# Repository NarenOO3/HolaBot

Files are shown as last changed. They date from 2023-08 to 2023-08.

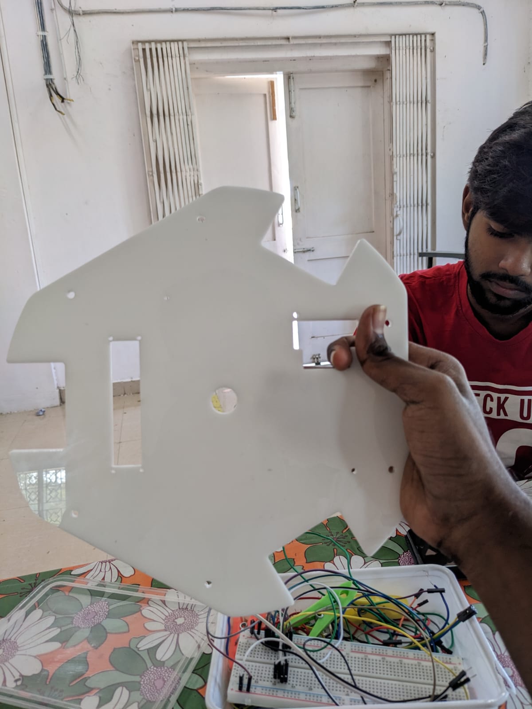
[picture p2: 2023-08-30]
Design Files/Lazer cut part.jpeg

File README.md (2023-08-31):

# HolaBot...
Hola bot is a 3- wheeled holonomic drive robot which can control all three degrees of freedom possible on a plane (Translation along the x and y-axis and rotation along the z-axis). Ultimately, we were required to create a Hola bot to draw complex art in the given plane. We did this Project as a team of four People for a competition called [eyantra](https://portal.e-yantra.org/)
# Video Demo (fast-forwarded)...

**Complete Hola Bot**

https://github.com/NarenOO3/HolaBot/assets/98276114/a756ce81-f39d-4ce2-9923-da0e97ca74d5

**Infinity Symbol**

https://github.com/NarenOO3/HolaBot/assets/98276114/4b2ce358-d221-415d-9932-d4c478116c63

# **Skills Learned :**
Linux, ROS, Gazebo, Solid Modeling, Python Programming, Arduino & C programming

# **Working Principle**
**Flow Chart**
Untitled Diagram drawio (1)

Initially the over Headcamera detect the aruco markers in the canvas and the aruco marker in the hola bot and send this information to the python node where we find the coordinates(x,y) of the Hola bot

| Arena (Canvas) |Aruco Markers |
| --- | --- |
| arena hola | Hola bot and aruco markers |

Then we will feed the picture that we like to draw as a contour and get the coordinates of the points in the contour which the holabot will draw and Using PID controller script,which subcribe the coordinates data of holabot from Over headcamera detection script, the Speed for the three stepper motor is decided which is sent to ESP32 in the hola bot via **wifi** through Socket Programming.

The Speed values in Esp32 will be send to ATmega2560 via hardware serial communication and Atmega2560 will control the stepper motors via A4988 Stepper Drivers.

# Design Pictures (done in Fusion 360)
| | |
| --- | --- |
| Chassis body final new v20 | Chassis body final new v23 |

# Gazebo Simulation Video
https://github.com/NarenOO3/HolaBot/assets/98276114/66dbb890-16b2-4fda-85fd-7b0090c1bab6

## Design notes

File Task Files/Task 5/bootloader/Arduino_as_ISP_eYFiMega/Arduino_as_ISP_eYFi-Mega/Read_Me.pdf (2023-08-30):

Flashing eYFi-Mega ATmega 2560 Bootloader using Arduino IDE

Note: Follow the procedure given below on Windows operating system ONLY.

### 1. Download Arduino IDE

Make sure you have Arduino IDE installed on your Windows system. If not, you can download it from https://www.arduino.cc/en/Main/Software.

### 2. Connections of Arduino Mega and eYFi-Mega board

Grab an Arduino Mega board. Make the connections as shown in below Fig. 1.

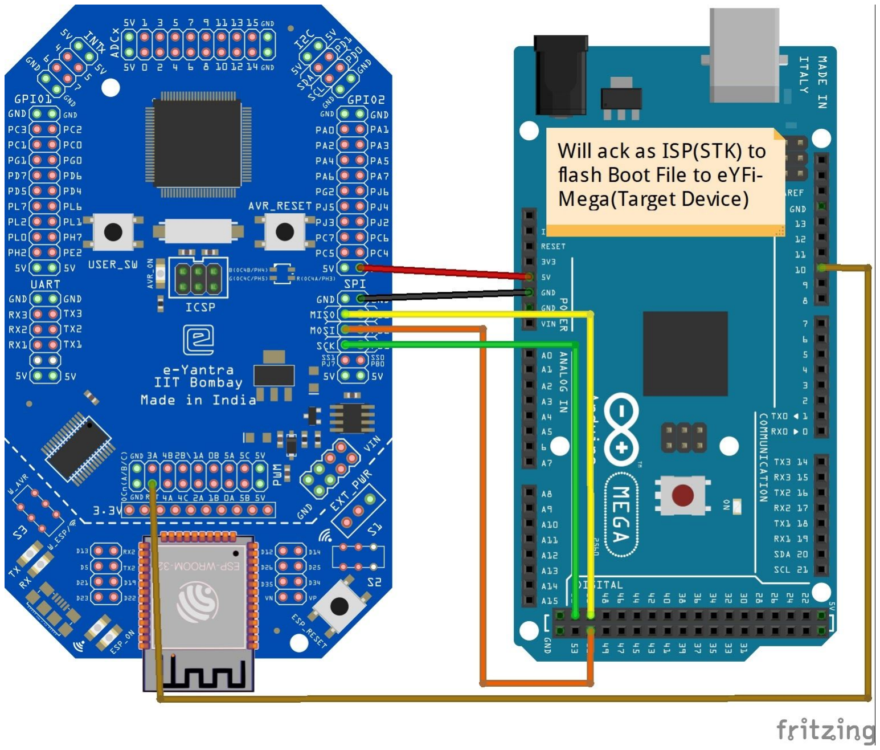
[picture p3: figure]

Fig. 1: Arduino as ISP Connections with eYFi-Mega board

### 3. Upload Arduino as ISP

Open the Arduino IDE. In the menu, select File > Examples > 11.ArduinoISP > ArduinoISP to open up the Arduino as ISP sketch.

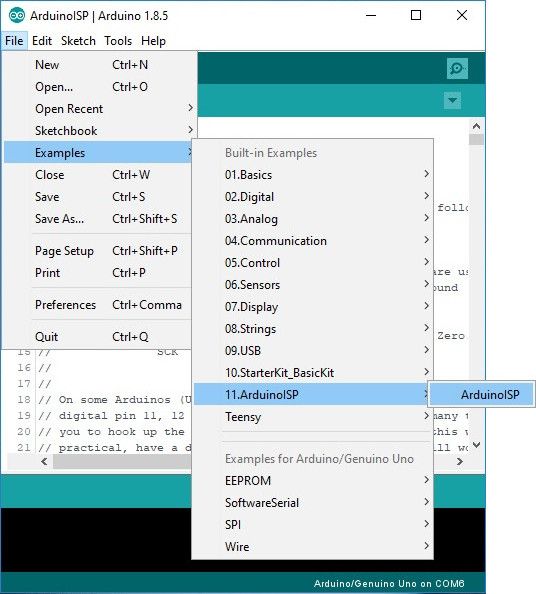
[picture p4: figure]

Select the COM port for your Arduino as ISP. The COM port may be different depending on how it is enumerated on your computer.
Note: Remember the COM port as it will be required in further sections.

Upload the code to your Arduino Mega to turn it into a AVRISP.

### 4. Burning a Bootloader to Your Target (eYFi-Mega)

Download the zip file “Arduino_as_ISP_eYFi-Mega” from the Downloads section of the link: http://products.e-yantra.org/.

Right-click on the file: fuseset.bat and click on Edit, this will open the file in Notepad to edit it.

First find the COM Port where the Arduino Mega board is connected to your system.
Edit the the command provided in the file and replace the default COM Port which is “COM58” and replace it with your COM Port. Save the files. Do Not change any other part of the command provided.

Repeat this step with the file: hexflash.bat, save the file after editing.

Open the Command Prompt, navigate to the Arduino_as_ISP_eYFi-Mega folder and run these two commands in the following order:
a. fuseset.bat
b. hexflash.bat

Expected Output after executing:

a. fuseset.bat

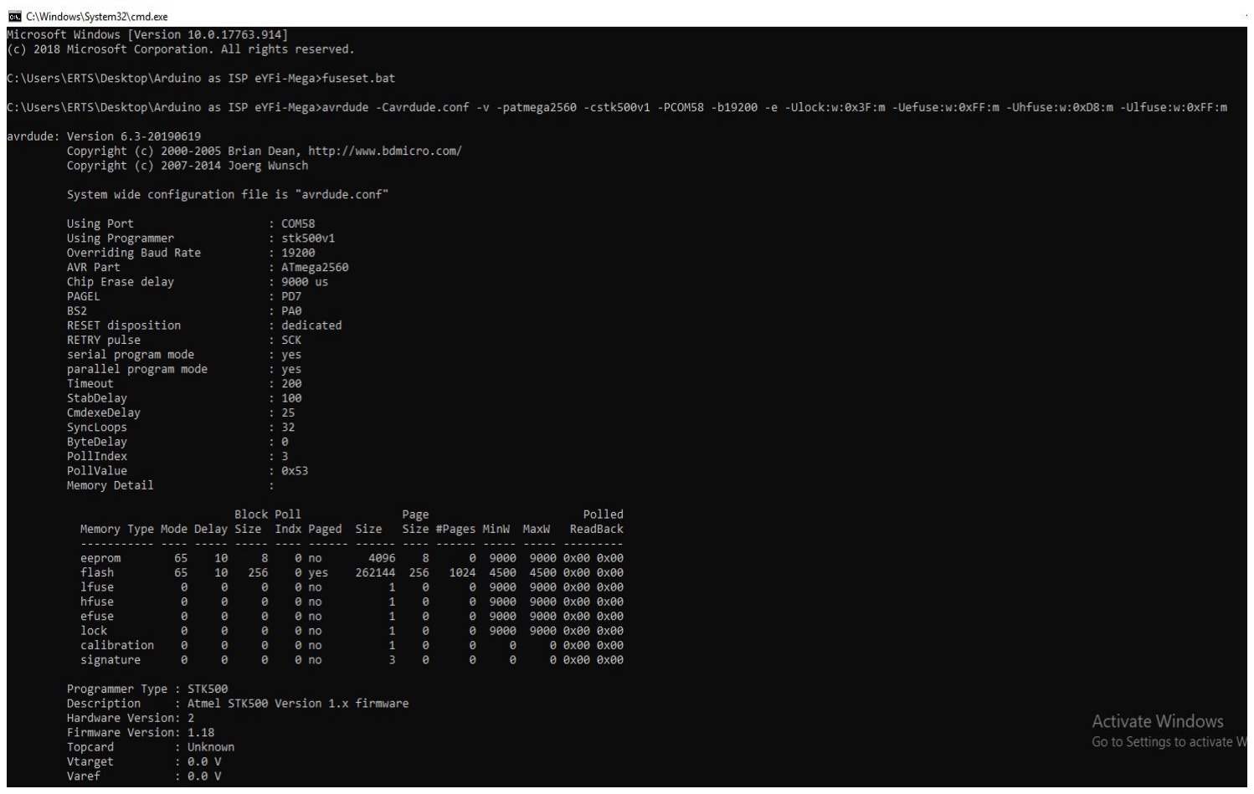
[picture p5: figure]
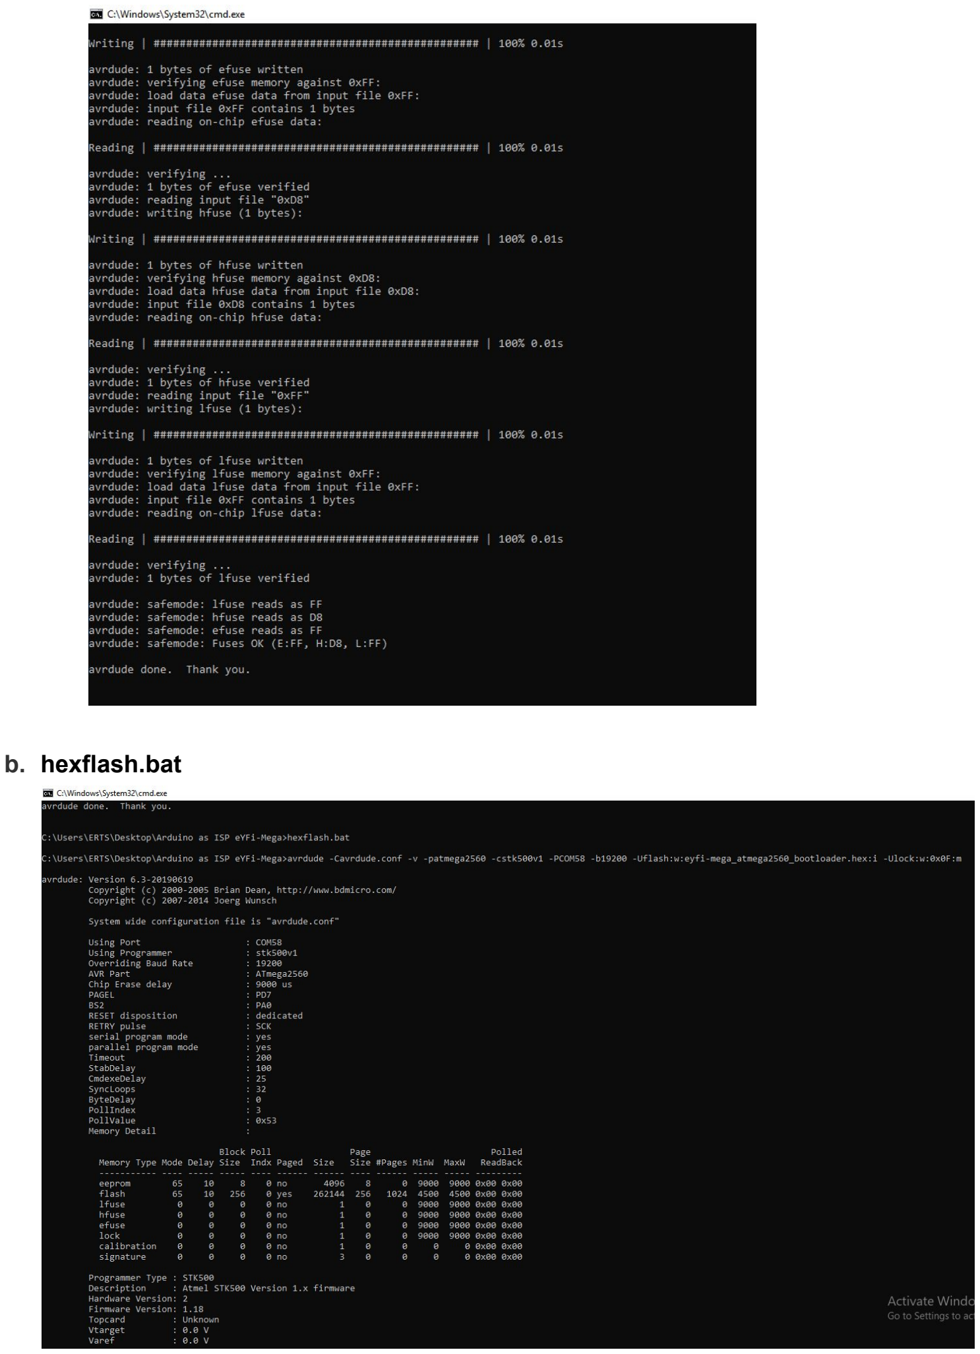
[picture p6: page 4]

b. hexflash.bat

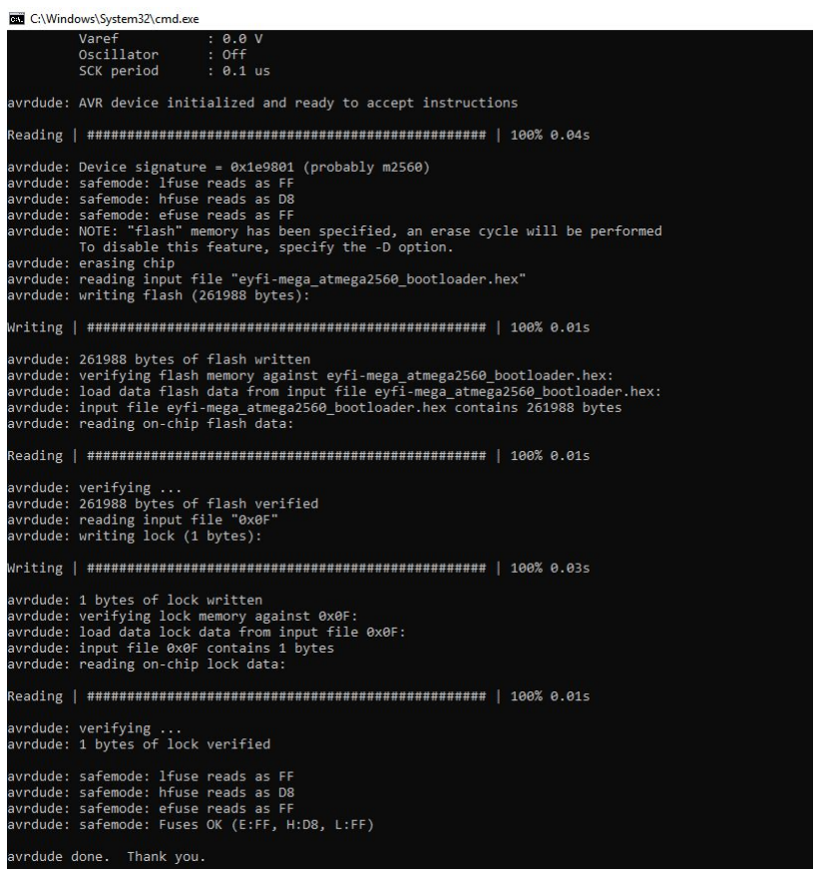
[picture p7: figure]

Once you get this similar output on your Command Prompt, this means that the eYFi-Mega ATmega2560 Bootloader has been flashed successfully on your board.

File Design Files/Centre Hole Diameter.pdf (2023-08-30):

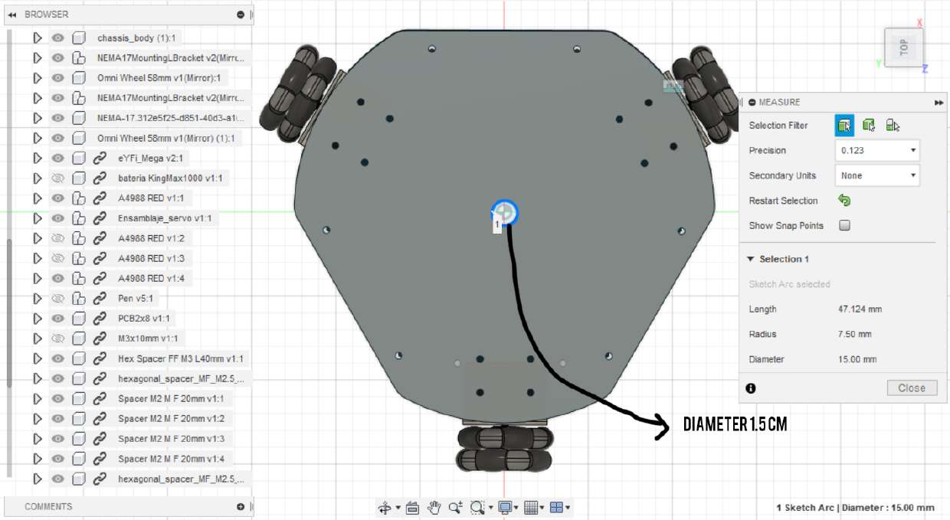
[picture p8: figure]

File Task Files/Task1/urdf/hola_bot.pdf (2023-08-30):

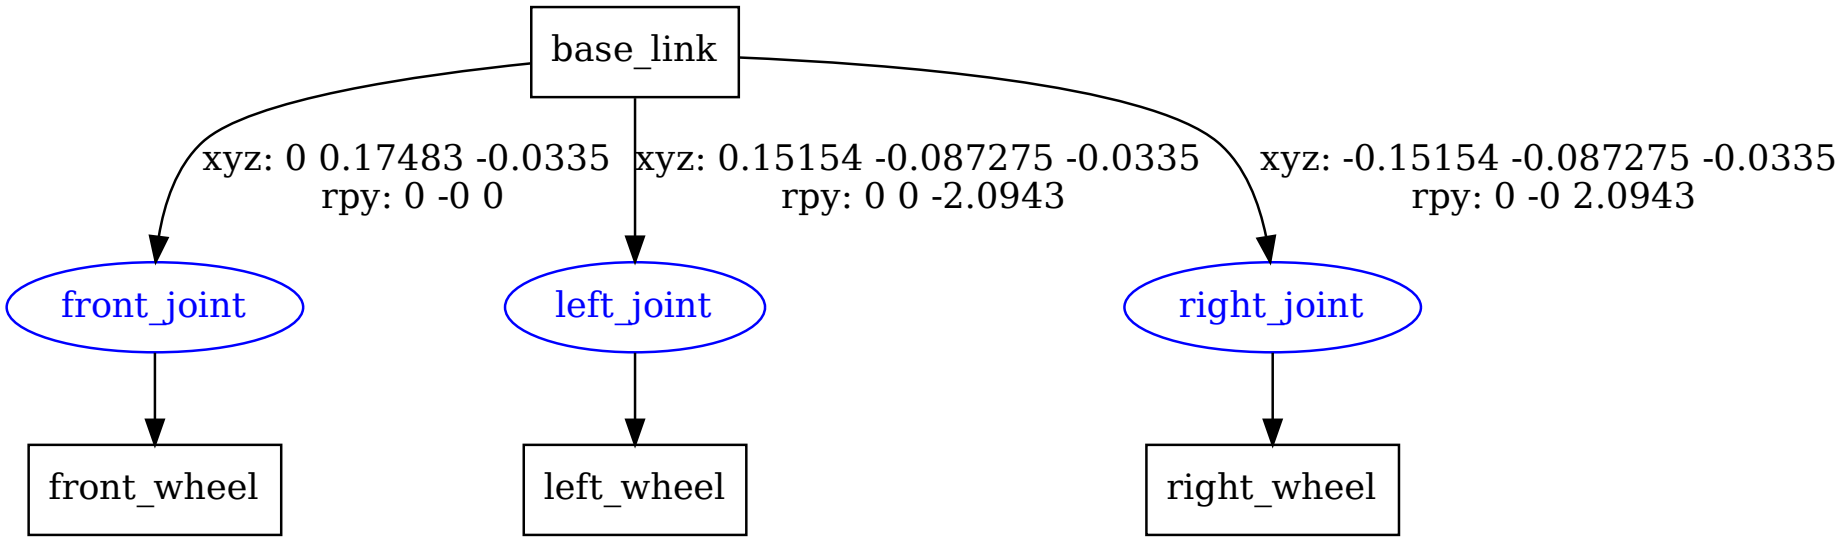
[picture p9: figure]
base_link; front_joint; xyz: 0 0.17483 -0.0335 rpy: 0 -0 0; left_joint; xyz: 0.15154 -0.087275 -0.0335 rpy: 0 0 -2.0943; right_joint; xyz: -0.15154 -0.087275 -0.0335 rpy: 0 -0 2.0943; front_wheel; left_wheel; right_wheel

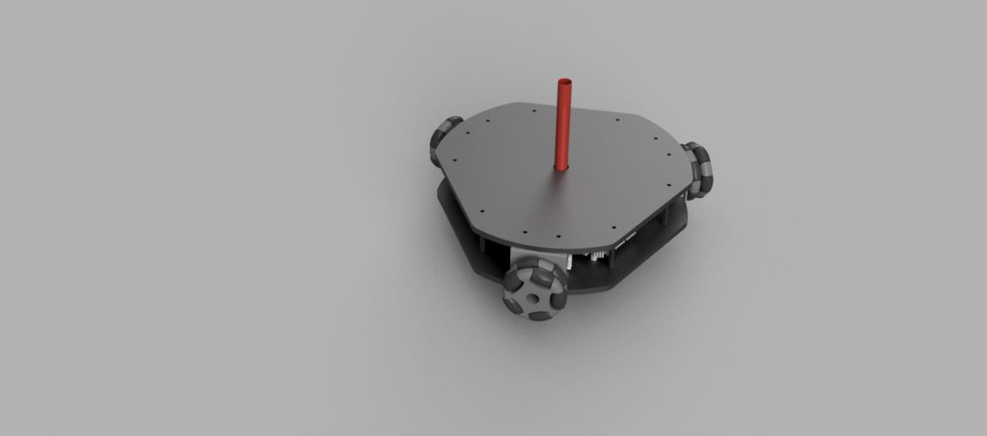
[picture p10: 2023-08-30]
Design Files/3D render of Design 8.jpeg

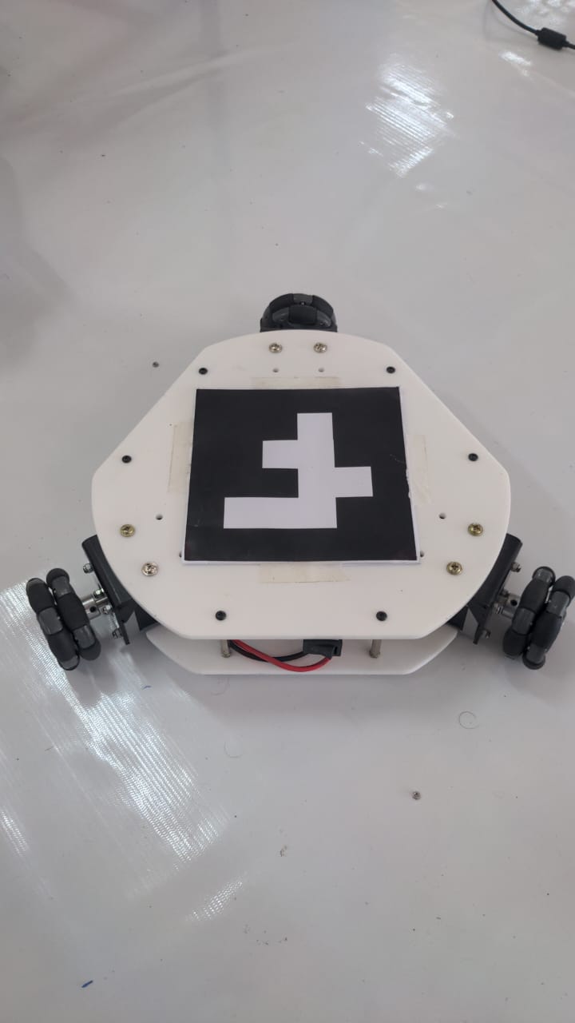
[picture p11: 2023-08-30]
Design Files/HolaBot.jpeg

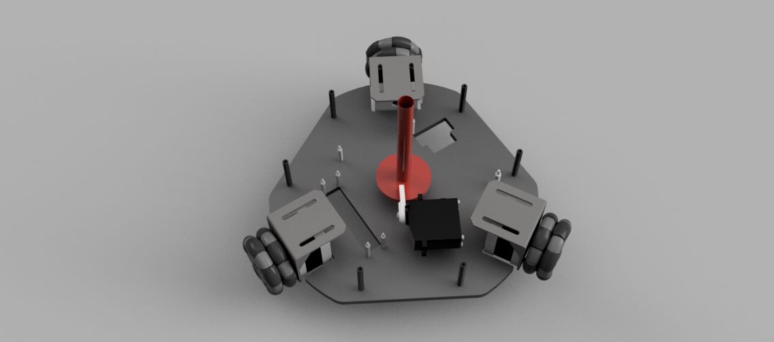
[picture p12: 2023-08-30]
Design Files/3D render of Design 4.jpeg

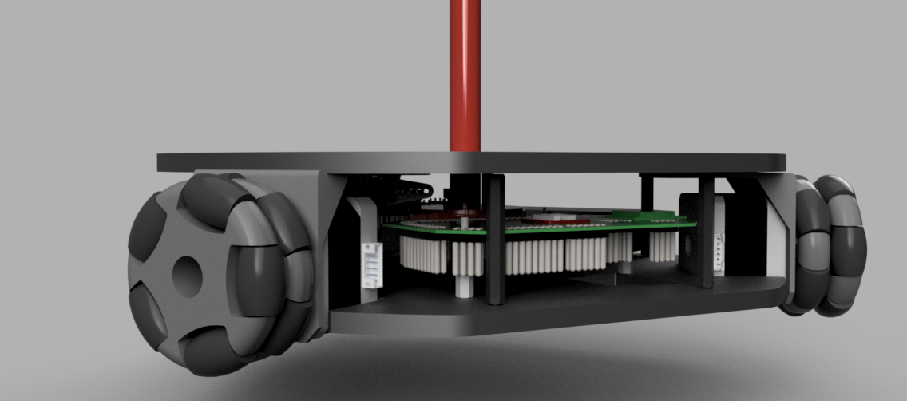
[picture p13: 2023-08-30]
Task Files/Task 4b/Chassis body final new v21.png

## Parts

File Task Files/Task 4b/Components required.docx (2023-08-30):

Components required:

Camera

Lora module

Arduino nano

Car parking lot system

Design a system that automatically counts how many cars inside the parking lot and display whether the parking lot is full or not and a parking barrier controlled by a servo that will allow the vehicle after the user pays for the parking ticket.

Components Required:

Arduino Uno

Ir sensor(s)

Serial Monitor

Servo

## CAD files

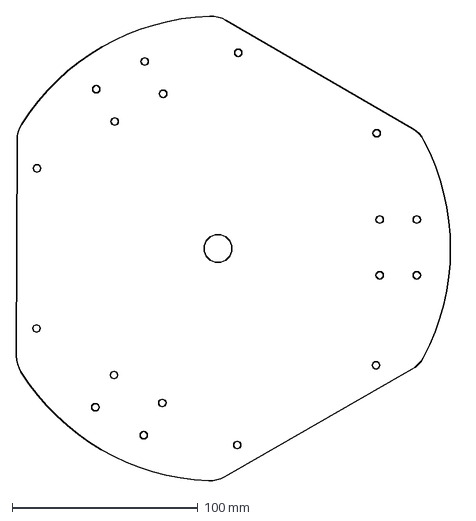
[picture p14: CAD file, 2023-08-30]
Design Files/Top Face of Hola BOT.dxf
238.3 x 250.0 mm

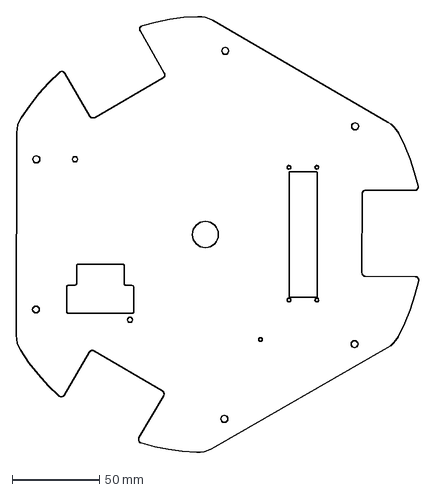
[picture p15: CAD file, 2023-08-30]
Task Files/Task 4b/Bottom Face of Hola BOT.dxf
230.7 x 250.0 mm

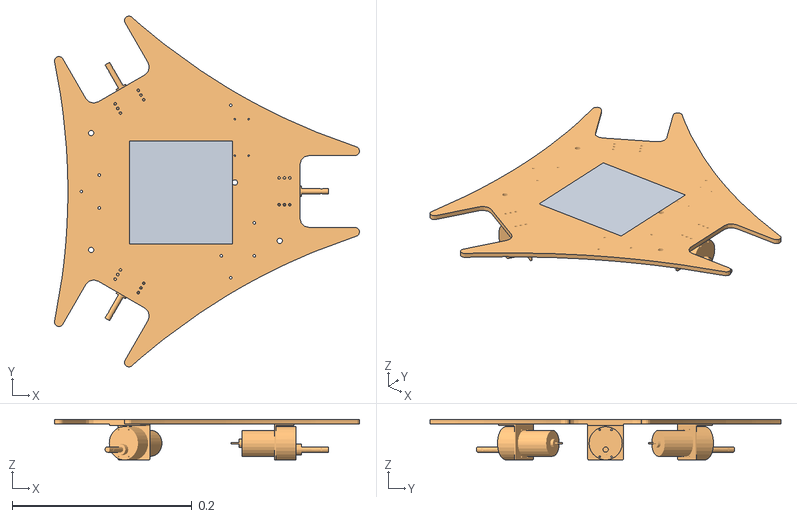
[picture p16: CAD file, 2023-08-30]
Task Files/Task2/meshes/base_link.obj
0.34 x 0.391 x 0.0454
Plane
Base_Link

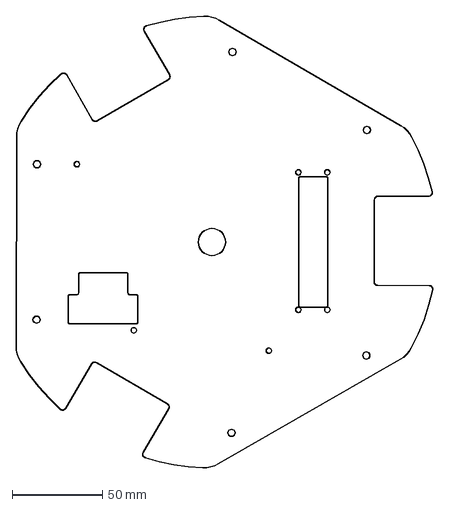
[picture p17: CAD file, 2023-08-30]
Design Files/Bottom Face of Hola BOT New.dxf
230.7 x 250.0 mm

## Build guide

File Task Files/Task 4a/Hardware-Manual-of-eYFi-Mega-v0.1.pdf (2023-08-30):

# Hardware Manual

## for eYFi-Mega Development Board

### Produced by: e-Yantra Team

### https://e-yantra.org/products/eyfi-mega

### Version: 0.1

### Dated: December 14, 2019

### About this Document

This document is created for all developers wanting to work with the eYFi-Mega development board. It provides the detailed description and specification of the board.

### Revision History

For revision history of this document, please refer to the Appendix A.

### Disclaimer and Copyright Notice

Information in this document, including URL references, is subject to change without notice. This document is provided as is with no warranties whatsoever, including any warranty or merchantability, non-infringement, fitness for any particular purpose, or any warranty otherwise arising out of any proposal, specification or sample. All liability, including liability for infringement of any proprietary rights, relating to use of information in this document is disclaimed. No licenses express or implied to any intellectual property rights are granted herein. The e-Yantra Products logo is a registered trademark.

Copyright ©2019 e-Yantra, ERTS Lab, CSE Dept., IIT Bombay, India.

1

## Table of Contents

1 Board Overview | 5
2 Hardware Description | 8
3 Power Management | 19
4 References | 20
Appendices | 21
A Revision History | 21
B Flashing Boot-loader on ATmega2560 | 22

2

C Flashing Boot-loader on ESP32 | 25

3

## List of Figures

1 | eYFi-Mega development board | | 5
2 | Block diagram of eYFi-Mega | | 8
3 | Functional diagram of eYFi-Mega | | 9
4 | eYFi-Mega Pinout Diagram for ATmega2560 | | 14
5 | eYFi-Mega Pinout Diagram for ESP32 | | 18
6 | Device Programming dialog box in Atmel Studio 7 | | 23
7 | Fuse settings to be done | | 23
8 | All OK message after programming the Fuses | | 24

## List of Tables

1 | Specifications of eYFi-Mega development board | | 7
2 | Functional Diagram of eYFi-Mega | | 9
3 | Partition Table of on-board ESP32 micro-controller | | 10
4 | Patterns of Wi-Fi status LED with various states of the board | | 11
5 | Function of Switches S1, S2 and S3 | | 13
6 | Switch positions for various programming modes | | 13
7 | Revision History of the document | | 21

4

# Board Overview

1

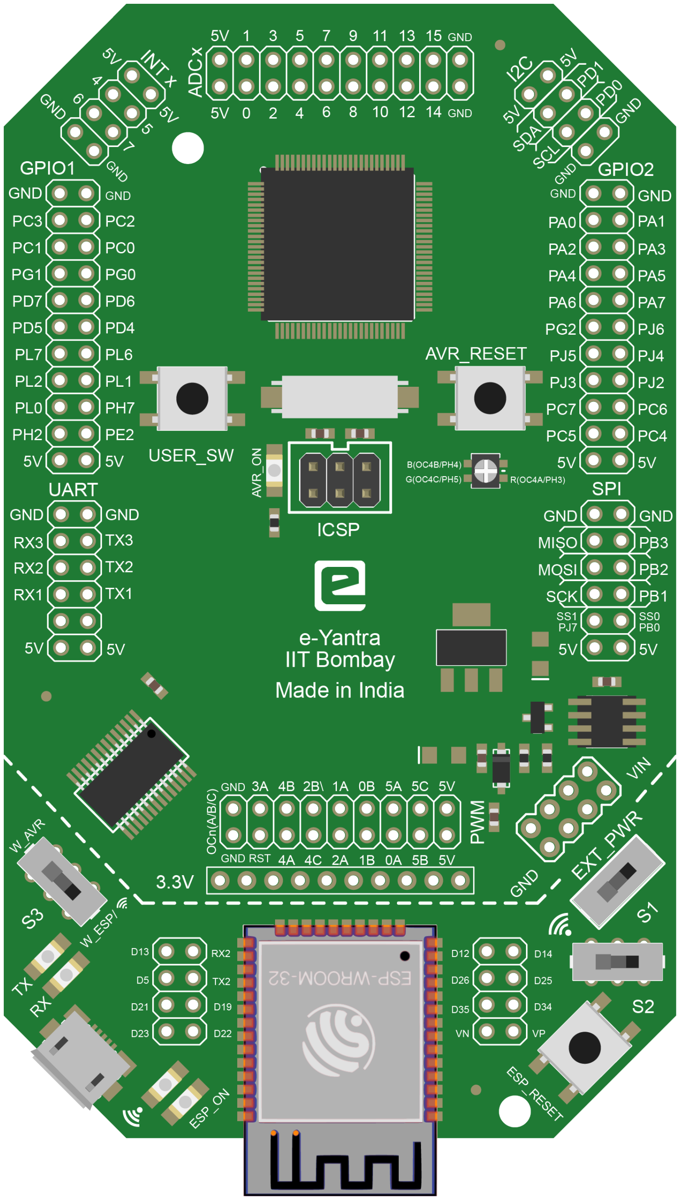
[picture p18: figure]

Figure 1: eYFi-Mega development board

The eYFi-Mega board provides an flexible and affordable way for users to try out new concepts and build prototype projects with the 8-bit ATmega2560 micro-controller in TQFP100 package and the 32-bit ESP32 micro-controller, choosing from the various combinations of performance, power consumption and features.
The eYFi-Mega board does not require any specialized hardware for programming as it comes with pre-installed bootloader file thus, the firmware on ATmega2560 and ESP32 can be easily updated either wired / wirelessly (Over-The-Air).
The eYFi-Mega board comes with the comprehensive support of Arduino Programming Language and Espressif IoT Development Framework (esp-idf ) which is the official development framework for the ESP32 chip.

The eYFi-Mega board comes with the pre-defined group of pins having the same functionality, making it easier for the developer to access and work with it.

### 1.1 Kit Contents

The eYFi-Mega Kit contains the following items:

- eYFi-Mega Development Board
- Interface Board
- USB micro-B plug to USB-A plug cable

### 1.2 Quick Start

For more information on the eYFi-Mega board and to access the documentation and tutorials, visit https://e-yantra.org/products/eyfi-mega.

### 1.2.1 Getting Started

Follow the sequence below to configure the eYFi-Mega and launch the demo software:

- Connect the eYFi-Mega board to a PC with a USB micro-B plug to USB-A plug cable through USB connector to power the board. The red LEDs AVR_ON and ESP_ON should light up.
- The RGB LED should light up and blink Red, Green and Blue colors in a sequence at the intervals of a second.
- Press button USER_SW (User Switch).
- Observe the change in colors on the RGB LED, by pressing the button USER_SW. It will glow the colors Yellow, Cyan, Magenta, Red, Green, Blue in a sequence. After this, the RGB LED will reset to the blinking of Red, Green and Blue color in the interval of a second.

### 1.2.2 System Requirements

- Linux: Ubuntu LTS 16.04 and 18.04
- USB micro-B plug to USB-A plug cable

### 1.2.3 Development Toolchains

- eY-IDE (Visual Studio Code extension)
- AVR-GCC
- ESP-IDF

### 1.3 Features

Your eYFi-Mega development board includes the following features:

- Dual Micro-controller Board | 8-bit ATmega2560 & 32-bit ESP32
- High Output Power | 12.5 W (5V, 2.5A)
- Wi-Fi | Protocol: 802.11 b/g/n (802.11n up to 150 Mbps), Frequency Range: 2.4 GHz 2.5 GHz
- Bluetooth Low Energy | Protocol: Bluetooth v4.2 BR/EDR and BLE specification
- On-board File Storage | 700 KB SPI-Flash File System (expandable up to 3 MB)
- Compatible with FreeRTOS | Both micro-controllers are capable of running FreeRTOS, ESP32 runs FreeRTOS out-of-the- box
- Arduino Programming Language | Both micro-controllers can be programmed using Arduino Programming Language

### 1.4 Specifications

Table 1 summarizes the specifications of the eYFi-Mega board.

Table 1: Specifications of eYFi-Mega development board

Parameter | Value
Board Supply Voltage | 4.75 VDC to 5.25 VDC from USB Micro-B cable (connected to a PC) 7.0 VDC to 21.0 VDC from External Power Supply
Dimensions | 107.95 mm x 64.01 mm x 24 mm (L x W x H)
Break-out power output | 3.3 VDC (800 mA max) 5.0 VDC (2.5 A max)
RoHS status | Compliant

# Hardware Description

2

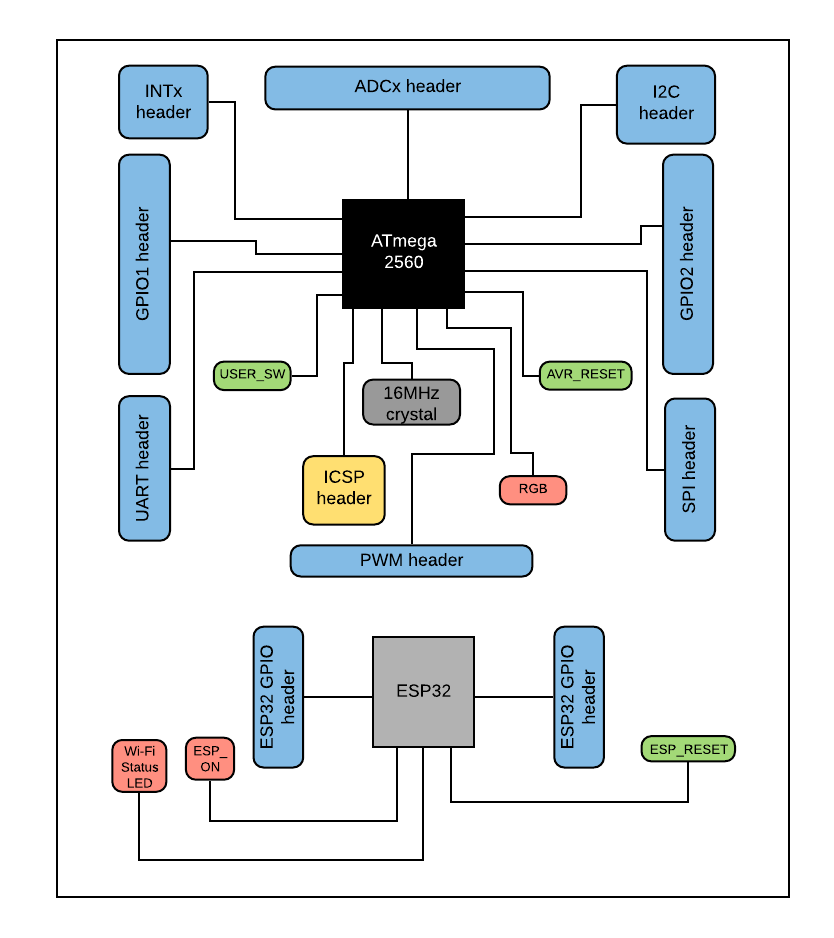
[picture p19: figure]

Figure 2: Block diagram of eYFi-Mega

The eYFi-Mega board includes ATmega2560 and ESP32 micro-controllers and a range of useful peripheral features (as the block diagram in Figure 2). This chapter describes how these peripherals operate and interface to the micro-controller.

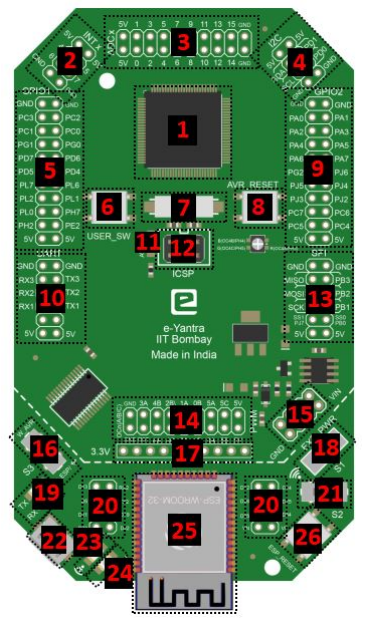
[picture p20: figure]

Figure 3: Functional diagram of eYFi-Mega

Table 2-1 summarizes the parts of the eYFi-Mega board with respect to the Figure 3.

Table 2: Functional Diagram of eYFi-Mega

# | Component Name | # | Component Name

1 | ATmega2560 micro-controller | 14 | PWM header
2 | INTx header | 15 | EXT_PWR header
3 | ADCx header | 16 | S3 switch
4 | I2C header | 17 | 3.3 V header
5 | GPIO1 header | 18 | S1 switch
6 | USER_SW push button | 19 | TX LED and RX LED
7 | 16 MHz crystal | 20 | ESP32 GPIO header
8 | AVR_RESET push button | 21 | S2 switch
9 | GPIO2 header | 22 | Micro-USB connector
10 | UART header | 23 | Wi-Fi Status LED
11 | AVR_ON LED | 24 | ESP_ON LED
12 | ICSP connector | 25 | ESP32 micro-controller
13 | SPI header | 26 | ESP_RESET push button

### 2.1 Functional Description

### 2.1.1 ATmega2560 micro-controller

ATmega2560 micro-controller is one of the most rich feature AVR micro-controller from Atmel featuring 256K Flash, 8K RAM, 86 I/O lines, 16 ADCs, 4 UARTs, 6 Timers, 8 Interrupts and much more.
All AVR micro-controllers can be programmed using ICSP, external programmer or bootloader. Advantage with the boot-loader is that you don’t need any external hardware to load the .hex file on the micro-controller. If Boot-loader firmware is loaded on the micro-controller then it can be programmed directly via serial port of USB using PC. We have already loaded the boot-loader firmware on ATmega2560 micro-controller. It is recommended that you always update the firmware on ATmega2560 either through wired via Micro-USB port or wirelessly i.e. Over-The-Air (OTA). For more information on how to update the firmware OTA, refer the Section Button - Wireless Flash in the Software Manual of eYFi-Mega development board.

### 2.1.2 ESP32 micro-controller

ESP32-WROOM-32 is a powerful, generic Wi-Fi+BT+BLE MCU module that targets a wide variety of applications, ranging from low-power sensor networks to the most demanding tasks, such as voice encoding, music streaming and MP3 decoding.
It has integrated SPI flash of 4 MB. We have partitioned this memory of on-board ESP32 to accommodate 1 MB OTA (Over-The-Air) application, 2 MB User application and 700 KB File Storage. This partition table can be modified by you as per your requirement. For example, if you want to increase or decrease the size of the 700 KB File Storage you can update the partition table. If you decide to modify the partition table for your project, you might not be able to use the OTA App because our OTA App is compatible with the partition table described below (Refer Table 3). In case you accidentally erase the partition you can download our Partition Table and our OTA App from our website. The current partition table is described below:

Table 3: Partition Table of on-board ESP32 micro-controller

Partition Name | Start Address | Size
reserved area (nvs, otadata, phy_init) | – | 300 KB
factory (ota-app) | 0x10000 | 1 MB
app1 (user-app) | 0x110000 | 2 MB
storage (spiffs) | 0x310000 | 700 KB

2.1.3 16 MHz crystal

The frequency of crystal connected to ATmega2560 is 16 MHz.

### 2.1.4 LEDs

1. AVR_ON
This Red colored LED indicates that the AVR chip ATmega2560 is powered ON.
2. ESP_ON
This Red colored LED indicates that the ESP32 chip is powered ON.
3. RGB LED
This is a tri-color user LED. It is a Common Anode type LED which is connected to ATmega2560 as follows:
(a) Red terminal is connected to OC4A / PH3.
(b) Green terminal is connected to OC4C / PH5.
(c) Blue terminal is connected to OC4B / PH4.
4. Wi-Fi Status LED
This Blue colored LED indicates whether any device is connected to the ESP32’s Wi-Fi access point. Once a device is connected, this LED glows. It is connected to ESP32 GPIO18 pin.
When you are connected to your eYFi-Mega over a Wi-Fi link, it is important to know the different states in which your board is. These states are indicated by this LED. Below is the description of different LED patterns associated with different states of the board.

Table 4: Patterns of Wi-Fi status LED with various states of the board

State | Wi-Fi Status LED Pattern
Wi-Fi client is connected to ESP32 | ON
Wi-Fi client disconnected from ESP32 | OFF
File Upload Start | OFF
File Upload End | Blink Fast for 100 ms
Firmware Flash Start | Blink Fast
Firmware Flash End - AVR | Blink Slow for 5 sec
Firmware Flash End - ESP32 | Blink Slow till S1 switch is toggled
5. TX LED and RX LED
- TX LED: This green colored LED indicates whether ATmega2560 or ESP32 is transmitting any information to the PC via wired connection.
- RX LED: This green colored LED indicates whether ATmega2560 or ESP32 is receiving any information to the PC via wired connection.

### 2.1.5 Switches

1. AVR_RESET
This push button is used to reset the AVR chip ATmega2560 micro-controller.
2. ESP_RESET
This push button is used to reset the ESP32 micro-controller.
3. USER_SW
This push button is a User Switch. It is connected to PE7 / INT7 pin of ATmega2560.
4. S1
This switch is used to decide which application code ESP32 should be running. If S1 is switched to the left side (indicated with a Wi-Fi symbol), ESP32 will run the Over-The-Air (OTA) application. This application turns ON the ESP32 Wi-Fi Access Point, listens and waits for any client to get connected with itself. It is also used for flashing the firmware for ATmega2560 and ESP32 wirelessly. If S1 is switched to right side, ESP32 will run the User application (which is flashed on ESP32 either via wired connection or wirelessly).
5. S2
This switch is used to make or break the connection between ATmega2560 and ESP32. If S2 is switched to left side (indicated with a Wi-Fi symbol), the UART0 TX, RX lines of ATmega2560 gets connected to the UART1 RX, TX lines of ESP32 respectively. Through this connection, one can send and receive any data between ATmega2560 and ESP32. If S2 is switched to right side, the connection between ATmega2560 and ESP32 breaks.
Note: Make sure that while flashing the firmware for ATmega2560 wirelessly, the S2 switch is on the left side.
6. S3
This switch is used to decide whether to flash firmware on ATmega2560 or ESP32 through wired connection. If S3 is switched to left side (indicated with W_AVR), one can flash firmware to ATmega2560 and if it is switched to right side (indicated with W_ESP/Wi-Fi symbol), one can flash firmware to ESP32 through wired connection. One can also use this switch for debugging purposes by printing data on the Wired Serial Monitor. For more information on Wired Serial Monitor, refer to the Section Button - Wired Serial Monitor in the Software Manual of eYFi-Mega development board.
Note: Make sure that while flashing the firmware for ATmega2560 wirelessly, the S3 switch is on the right side.

Table 5 highlights the function of Switches S1, S2 and S3 in short.
Table 6 summarizes the use of the Switches S1, S2 and S3 and their positions for flashing the firmware on ATmega2560 and ESP32 via wired connection or wirelessly (OTA).

Table 5: Function of Switches S1, S2 and S3

Switch | Function
Switch #1 (S1) | ESP32 Partition Selection Switch (OTA-App / User-App selection) Using this switch you can toggle between OTA application and User application on ESP32
Switch #2 (S2) | Toggle ESP32 UART#1 connection with ATmega2560 UART#0 This switch can make or break connection between UART#1 of ESP32 and UART#0 of ATmega2560
Switch #3 (S3) | Wired ATmega2560 or Wired ESP32 Using this switch you can select which micro-controller you want to wire-program

Table 6: Switch positions for various programming modes

Programming Mode | S1 Position (towards) | S2 Position (towards) | S3 Position (towards)
ATmega2560 Wired | – | – | W_AVR
ATmega2560 Wireless | Wi-Fi symbol | Wi-Fi symbol | W_ESP / Wi-Fi symbol
ESP32 Wired | – | – | W_ESP / Wi-Fi symbol
ESP32 Wireless | Wi-Fi symbol | Wi-Fi symbol | W_ESP / Wi-Fi symbol

### 2.1.6 ICSP connector

This is a six-pin ICSP (In-Circuit Serial Programming) or ISP (In-System Programming) header of ATmega2560. For more details about ISP and boot-loader, refer to Section 2.1.1. The ICSP connector pins are shown in Figure 4.
Note: If you use ISP programmer with the eYFi-Mega board and try to load .hex file on to ATmega2560 then boot section code will get erased and the ATmega2560 will no longer be programmable via wired connection or wirelessly. In case you accidentally erase the boot section code you can always download the Boot-loader firmware from the website and flash it on ATmega2560 using ISP programmer through the ICSP header pins. To know about how to flash the boot-loader firmware on ATmega2560, refer to Appendix B.

### 2.1.7 GPIO1 header

This header is a group of pins of ATmega2560 that can be used as General Purpose Input Output (GPIO) to connect any input or output peripheral devices. Apart from using these pins as GPIO, they also have certain alternative functions, the details of the same is shown in Figure 4. This header also has two pins of VCC i.e. 5V and GND each.

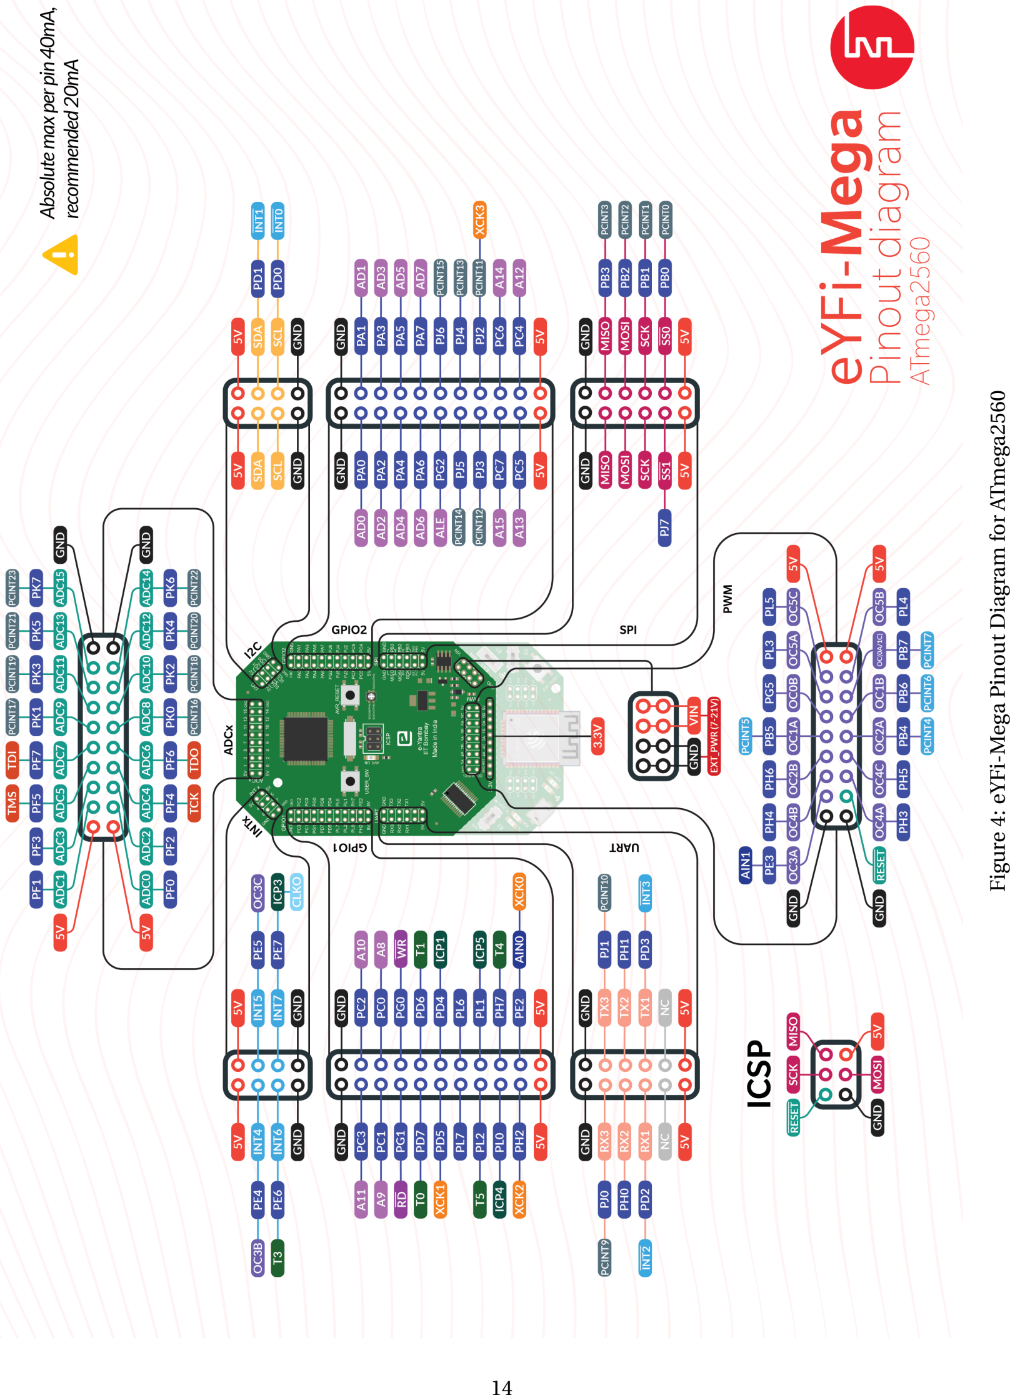
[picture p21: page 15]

Figure 4: eYFi-Mega Pinout Diagram for ATmega2560

### 2.1.8 GPIO2 header

This is another header which is also a group of pins of ATmega2560 that can be used as General Purpose Input Output (GPIO) to connect any input or output peripheral devices. Apart from using these pins as GPIO, they also have certain alternative functions, the details of the same is shown in Figure 4. This header also has two pins of VCC i.e. 5V and GND each.

### 2.1.9 INTx header

This header is a group of pins of ATmega2560 that can be used as External Hardware Interrupt (INT) sources. There are eight External Interrupt sources from INT7 to INT0 in ATmega2560. The Interrupt sources INT7:4 are present on this header. The other four Interrupt sources INT3:0 are also available on the board but are not present on this header, since they have other alternate functions which are given more priority. These pins INT3:0 can be found in Figure 4. The x in the header name INTx stands for Interrupt source number and ranges from 7 to 4 for this board. Apart from using these pins as External Interrupts, they also have certain alternative functions, the details of the same is shown in Figure 4. This header also has two pins of VCC i.e. 5V and GND each.

### 2.1.10 ADCx header

This header is a group of pins of ATmega2560 that can be used as analog inputs or channels for the Analog to Digital Converter (ADC) inside the micro-controller. There are sixteen ADC channels from ADC15 to ADC0 in ATmega2560. All ADC channels are present on this header. The x in the header name ADCx stands for ADC channel and ranges from 16 to 0. Apart from using these pins as ADC channels, they also have certain alternative functions, the details of the same is shown in Figure 4. This header also has two pins of VCC i.e. 5V and GND each.

### 2.1.11 I2C header

This header is a group of pins of ATmega2560 that can be used as 2-wire Serial Interface Data and Clock for Inter-Integrated Circuit (I2C or I²C) protocol in the micro-

controller. The SDA or PD1 are two names of the same pin of micro-controller. Similarly, SCL or PD0 are two names of the same pin of micro-controller. Apart from using these pins as I²C serial data and clock, they also have certain alternative functions, the

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

### 2.1.12 UART header

This header is a group of pins of ATmega2560 that can be used as Transmit (TX) and Receive (RX) Data pins for Universal Asynchronous Receiver and Transmitter (UART)

protocol in the micro-controller. There are four UART modules from UART3 to UART0 in ATmega2560. The TX and RX pins of UART3:1 are present on this header. The TX and RX pins of UART0 is not made available on the board. Apart from using these pins as TX and RX pins of UART module, they also have certain alternative functions, the details of the same is shown in Figure 4. This header also has two pins of VCC i.e. 5V and GND each.

### 2.1.13 SPI header

This header is a group of pins of ATmega2560 that can be used as Bus pins for Serial Peripheral Interface (SPI) protocol in the micro-controller. The MISO or PB3 are two names of the same pin of micro-controller. Similarly, MOSI or PB2 and SCK or PB1 are two names of the same pin of micro-controller. The other name for the Slave Select pin SS0 is PB2. There is only one Slave Select pin available in ATmega2560, but for interfacing multiple devices via SPI protocol, one can configure any GPIO pin as Slave Select. We have provided one such GPIO pin PJ7 and named it as SS1. Apart from using these pins as Bus pins of SPI, they also have certain alternative functions, the details of the same is shown in Figure 4. This header also has two pins of VCC i.e. 5V and GND each.

### 2.1.14 PWM header

This header is a group of pins of ATmega2560 that can be used as Output Compare or Pulse Width Modulation (PWM) pins for the Timers in the micro-controller. There are two 8-bit Timers, Timer 0 and 2 and four 16-bit Timers, Timer 1, 3, 4 and 5 in ATmega2560. 8-bit Timers have two PWM Channels named as OCnA and OCnB where n stands for Timer number and will be of value 0 and 2. 16-bit Timers have four PWM Channels named as OCnA, OCnB and OCnC where n stands for Timer number and will be of value 1, 3, 4 and 5. Total 14 PWM Channels available on this header, they are: OC0A, OC0B, OC1A, OC1B, OC1C, OC2A, OC2B, OC3A, OC4A, OC4B, OC4C, OC5A, OC5B and OC5C. The PWM channel OC0A and OC1C are two names of the same pin of micro-controller. The PWM channels OC3B and OC3C are not present on this header, since they have other alternate functions which are given more priority. These channels OC0A and OC1C can be found in Figure 4. The x in the header name OCn(A/B/C) stands for Timer number and ranges from 5 to 0. Apart from using these pins as Output Compare or PWM channel, they also have certain alternative functions, the details of the same is shown in Figure 4. This header also has two pins of VCC i.e. 5V and GND each. Also, the RESET pin of ATmega2560 is available on this header.

### 2.1.15 ESP32 GPIO header

This is divided into two headers, each of 2 x 4 pins header. These are the pins of ESP32 and are named with their default functionality of GPIO. Apart from using these pins as GPIO, they also have certain alternative functions, the details of the same is shown in

Figure 5. This header also has Transmit (TX) and Receive (RX) Data pins of UART2 of ESP32.

### 2.1.16 Micro-USB connector

This is a Micro-USB port where a USB micro-B plug to USB-A plug cable can be connected to the PC. It can be used to flash the firmware on ATmega2560 or ESP32 via wired connection. Also, one can connect the board to PC via this connector for the debugging purposes by printing data on the Wired Serial Monitor.

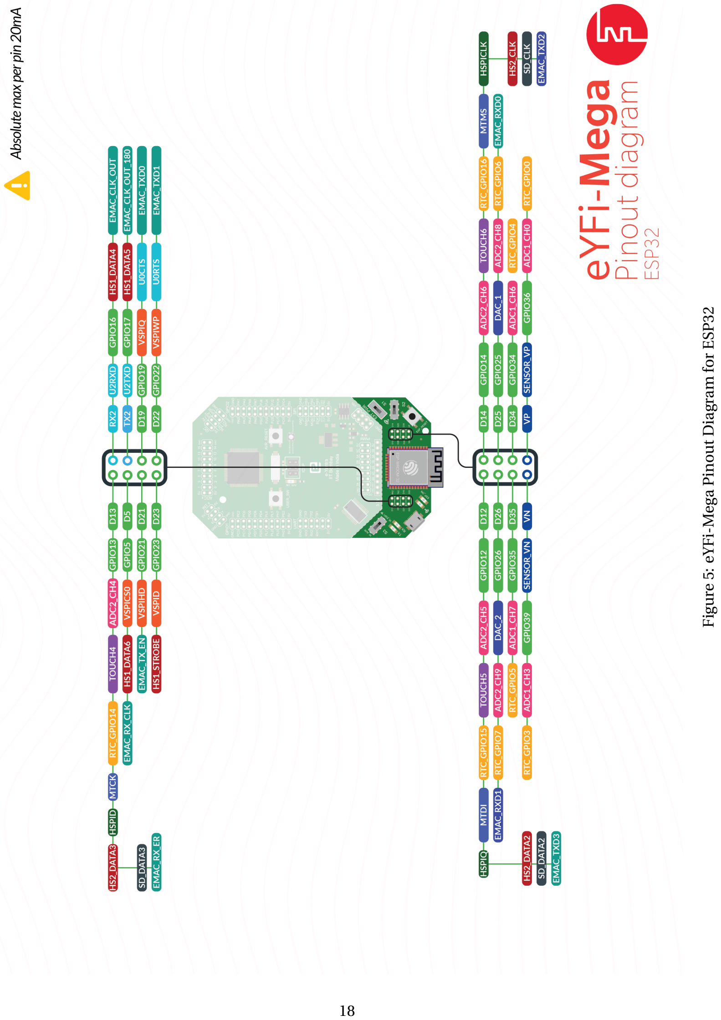
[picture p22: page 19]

Figure 5: eYFi-Mega Pinout Diagram for ESP32

# Power Management

3

### 3.1 5V DC Supply

There are multiple 5VDC supply available on the board, which one can use to power multiple devices easily and there will be no need to divide the supply further.

### 3.2 3.3V header

This header is a group of pins that provide 3.3VDC supply. Maximum of 800 mA current can be drawn from these pins, but if high current is drawn from these pins, it will also affect the power delivered to ESP32 and will reduce its Wi-Fi signal strength.

### 3.3 EXT_PWR header

This header is a group of pins where the eYFi-Mega board can be powered by an External DC Supply. These pins are divide into VIN and GND each having four pins. The positive terminal of External DC Supply should be connected to any of the four VIN pins and the negative terminal should be connected to any of the four GND pins. The External DC Supply Voltage should strictly be within the range 7.0 VDC to 21.0 VDC.
When the board is powered from External DC Supply, typically 1A and maximum 2.5A current can be drawn from the 5V pins. But if current more than 1.5A is drawn from the 5V pins, one has to use cooling mechanism as the board will become hot on drawing larger currents.

# References

4

In addition to this document, the following references will be helpful:

1. ATmega2560 datasheet, available at https://ww1.microchip.com/downloads/en/devicedoc/atmel-2549-8-bit-avr-microcontroller-atmega640-1280-

1281-2560-2561_datasheet.pdf (https://ww1.microchip.com/downloads/en/devicedoc/atmel-2549-8-bit-avr-microcontroller-atmega640-1280-1281-2560-2561_datasheet.pdf)

2. ESP32-WROOM32 datasheet, available at https://www.espressif.com/sites/default/files/documentation/esp32-wroom-32_datasheet_en.pdf (https://www.espressif.com/sites/default/files/documentation/esp32-wroom-32_datasheet_en.pdf)
3. Espressif IoT Development Framework (ESP-IDF) Programming Guide, available at https://docs.espressif.com/projects/esp-idf/en/stable/index.html
4. I2C Protocol explained
(a) by Sparkfun: https://learn.sparkfun.com/tutorials/i2c
(b) by Texas Instruments (TI) http://www.ti.com/lit/an/slva704/slva704.

pdf (http://www.ti.com/lit/an/slva704/slva704.pdf)

5. SPI Protocol explained
(a) by Sparkfun: https://learn.sparkfun.com/tutorials/serial-peripheral-

interface-spi (https://learn.sparkfun.com/tutorials/serial-peripheral-interface-spi)

(b) by electroSome https://electrosome.com/spi/

# Appendices

# Revision History

A

Table 7: Revision History of the document

Date | Version | Release notes
December 14, 2019 | v0.1 | First release of the document

# Flashing Boot-loader on ATmega2560

B

Note: Refer to this section only if you have accidentally overwritten the Boot-loader firmware of ATmega2560 on eYFi-Mega board.

Follow each of the steps given below carefully:

1. Components and Software required to get started:
(a) eYFi-Mega board
(b) USB micro-B plug to USB-A plug cable
(c) USB A-Male to B-Male cable
(d) Atmel AVRISP mkII (for more details, refer to link) (http://ww1.microchip.com/downloads/en/DeviceDoc/Atmel-42093-AVR-ISP-mkII_UserGuide.pdf)
(e) Atmel Studio 7 software (only on Windows platform)

(f ) Boot-loader firmware of ATmega2560 micro-controller on eYFi-Mega board (can be downloaded from Downloads section on eYFi-Mega page, link: https: //e-yantra.org/products/eyfi-mega).

2. Connect the USB A-Male to B-Male cable to the PC and Atmel AVRISP mkII.
3. Connect the 6-pin AVR ISP FRC cable of Atmel AVRISP mkII to the ICSP header on eYFi-Mega board.
Note: The notch on the FRC cable should match with the notch provided around the ICSP header.
4. Connect the USB micro-B plug to USB-A plug cable to the PC and Micro-USB connector on eYFi-Mega board.
5. Once the above connections are done, check the LED status on Atmel AVRISP mkII. If the LED color is Green, this means that everything is working fine and you can proceed with the next step. But, if the LED color is Orange or Red, this means that the connections between the Atmel AVRISP mkII and eYFi-Mega board is weak.

6. Open the Atmel Studio 7 software. Select the option Device Programming or use the shortcut Ctrl + Shift + P. A dialog box will open as shown in Figure 6.
7. Under Tool option, select AVRISP mkII.
8. Under Device option, select ATmega2560.
9. Under Interface option, select ISP.
10. Click on Apply.
11. Click on Read to read the Device Signature.
12. Check whether the Device Signature value is 0x1E9801 and the Target Voltage is around 5V.
13. Go to Fuses and select the Fuse settings as shown in the Figure 6.

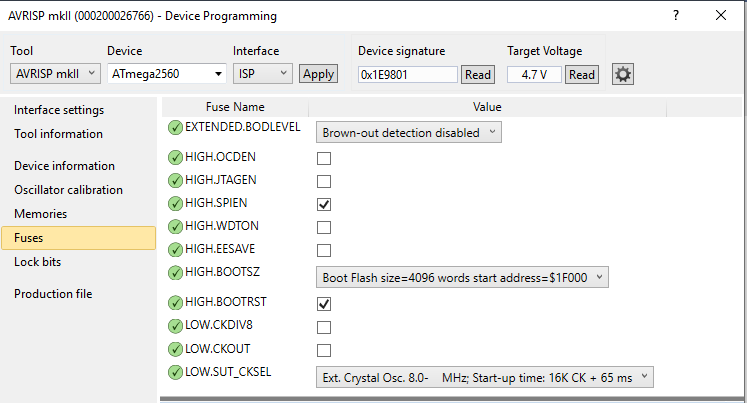
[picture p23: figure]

Figure 6: Device Programming dialog box in Atmel Studio 7

14. Make sure that the option of Auto read and Verify after programming are selected as shown in Figure 6.

Figure 7: Fuse settings to be done

15. Once you are done with the above settings, click on Program.

16. After the programming is complete, you will see the message as shown in the below Figure 6.

Figure 8: All OK message after programming the Fuses

17. Go to Memories, select Erase Now to erase the ATmega2560 chip before flashing the Boot-loader firmware on to it.
18. Make sure the options Erase device before programming and Verify flash device after programming are selected.
19. Select the Boot-loader firmware downloaded under the Flash (256 KB) section and press Program.
20. Once the programming is complete, you will get the message: Verifying Flash....OK. The LED color on Atmel AVRISP mkII will turn to Orange and will blink continuously.
21. Congrats! Your eYFi-Mega board is updated with the Boot-loader firmware of ATmega2560.

# Flashing Boot-loader on ESP32

C

Note: Refer to this section only if you have accidentally overwritten the Boot-loader firmware / Partition Table / OTA Application of ESP32 on eYFi-Mega board.

1. To upload the Boot-loader firmware of ESP32: refer the Section Flashing eYFi-Mega ESP32 Bootloader in the Software Manual of eYFi-Mega development board.
2. To upload the Partition Table of ESP32: refer the Section Flashing eYFi-Mega ESP32 Partition Table in the Software Manual of eYFi-Mega development board.
3. To upload the OTA Application of ESP32: refer the Section Flashing eYFi-Mega ESP32 OTA Application in the Software Manual of eYFi-Mega development board.

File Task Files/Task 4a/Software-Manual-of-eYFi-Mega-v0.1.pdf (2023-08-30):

## eYFi-Mega

# Software Manual v0.1

### 1 December 2019

Installation of VS Code in Linux | 2
Download and Install VS Code | 3
Enable Portable Mode | 4
Start VS Code Portable | 5
VS Code User Interface | 7
Disable Update VS Code Pop Up | 10
Installation of eYFi-Mega Extension and Toolchains in Linux | 10
Installation of eYFi-Mega Extension | 10
Installation of AVR Toolchain for ATMega 2560 | 13
Installation of ESP-IDF and Xtensa Compiler for ESP32 | 15
Dial Out | 19
Using eYFi-Mega Extension | 19
Buttons of eYFi-Mega Extension | 19
Button - Create Project | 20
Button - Open Project | 22
Button - Compile | 22
Button - Wired Flash | 23
Button - Wireless Flash | 25
Button - eYFi File Server | 27
Button - Wired Serial Monitor | 28
Status Bar | 29
Keyboard Shortcuts | 29
Build System | 31
ATMega 2560 Build System | 31
ESP32 Build System | 31
Using Makefile Commands | 32
Adding Third-Party Libraries | 33
eYFi-Mega OTA Application | 34
eYFi-Mega File Server | 34
Set Wi-Fi SSID and Password | 35
Default SSID and Password of eYFi-Mega Wireless Access Point | 35
Wi-Fi Status LED Indication | 36

eYFi-Mega Wireless Serial Terminal Application | 36
eYFi-Mega ESP32 Partition Table | 38
Flashing ESP32 Bootloader, Partition Table, OTA Application, Wireless Serial
Terminal Application and ESP32 User Application in eYFi-Mega | 38
Flashing eYFi-Mega ESP32 Bootloader | 39
Flashing eYFi-Mega ESP32 Partition Table | 39
Flashing eYFi-Mega ESP32 OTA Application | 39
Flashing eYFi-Mega ESP32 User Application and Wireless Serial Terminal
Application | 39
APPENDIX | 40
APPENDIX A: Kill Any Command | 40
APPENDIX B: Unix and Blank Spaces | 40
APPENDIX C: Set Python 2 as your default Python Interpreter | 40

## Installation of VS Code in Linux

There are several IDEs available to program AVR Microcontrollers and ESP32 but for eYFi-Mega, we have developed a special extension for VS Code which makes it convenient to program and use features of the development board. In this section, we will discuss how to install the VS Code and in the next section, we will see how to install the extension.

NOTE: For all the software required to work properly make sure that Python 2 is set as your default Python Interpreter. We recommend you to go through Appendix C before you proceed with the installation.

Download and Install VS Code

### 1. Download the portable version of the IDE which can be found at this URL

a. 64 Bit Linux: https://code.visualstudio.com/docs/?dv=linux64
b. 32 Bit Linux: https://code.visualstudio.com/docs/?dv=linux32

### 2. Extract the .tar.gz file at any desired location to install the VS Code

in your machine. We recommend to extract it in a folder in your home directory. To do so execute the following commands,

$ cd ~/Downloads
$ mkdir ~/eYFi-IDE
$ tar -xvzf code-stable-1574694065.tar.gz -C ~/eYFi-IDE/

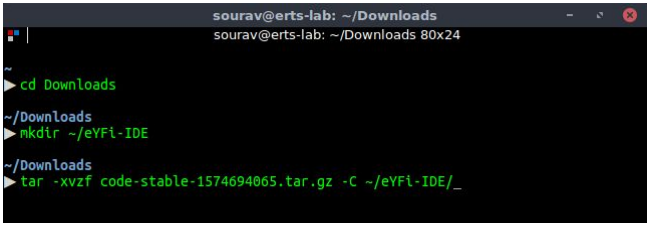
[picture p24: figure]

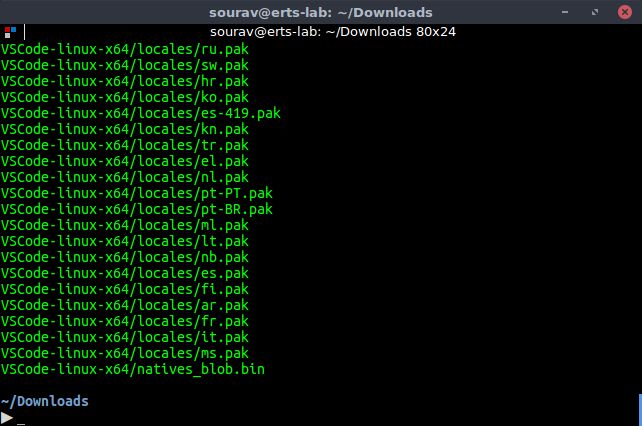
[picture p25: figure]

Enable Portable Mode

Visual Studio Code needs to be run in Portable Mode. This mode enables all data created and maintained by the VS Code to live near itself, so it can be moved around across environments.

After unzipping the VS Code download, simply create a “data” folder within Code's folder:

|- ~/eYFi-IDE/VSCode-linux-x64

| | |- code (the executable file)
| | |- data

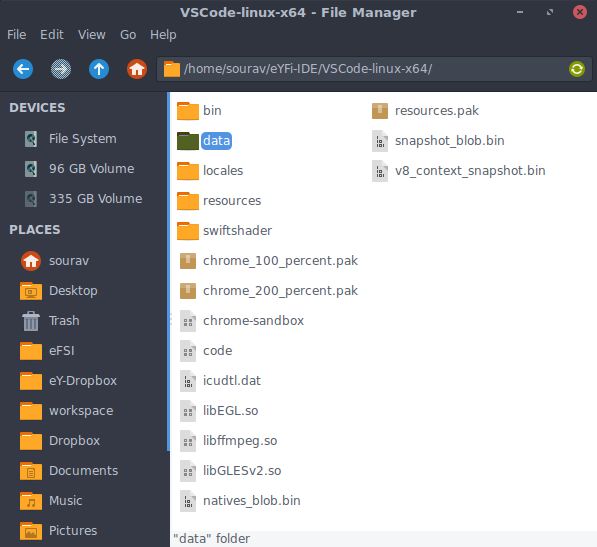
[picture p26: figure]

From then on, that folder will be used to contain all Code data, including session state, preferences, extensions, etc.

The data folder can be moved to other VS Code installations. This is useful for updating your portable Code version: simply move the data folder to a newer extracted version of the VS Code.

Start VS Code Portable

Open terminal in the root folder of the VS Code portable.

### 1. Make the “code” file executable. To do this use this command:

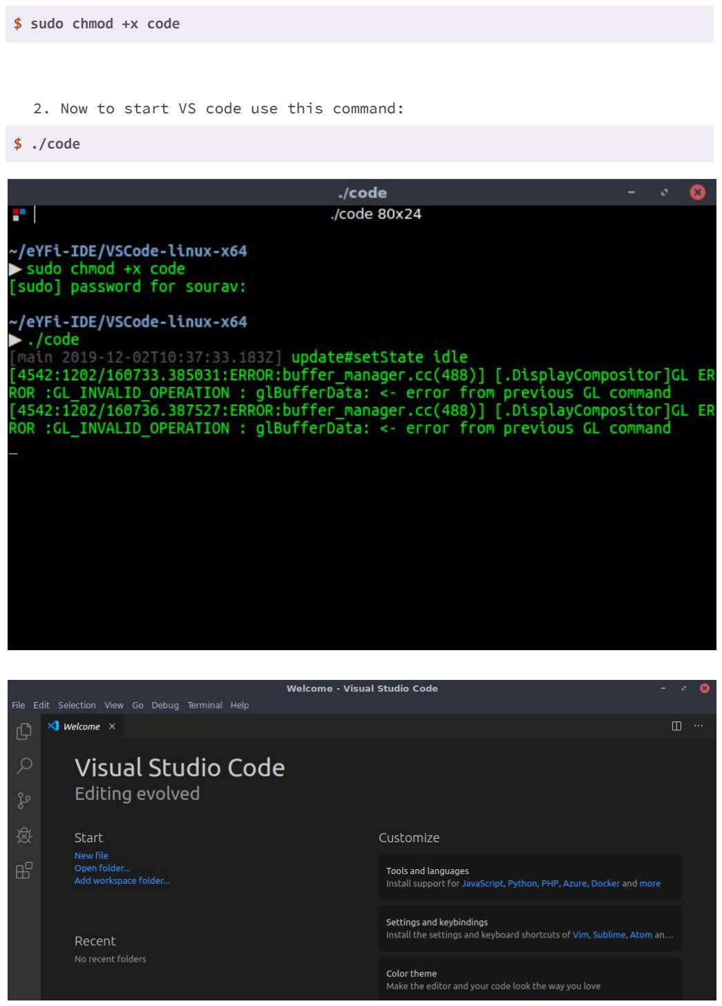
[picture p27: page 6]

$ sudo chmod +x code

### 2. Now to start VS code use this command:

$ ./code

VS Code User Interface

At its heart, Visual Studio Code is a code editor. Like many other code editors, VS Code adopts a common user interface and layout of an explorer on the left, showing all of the files and folders you have access to, and an editor on the right, showing the content of the files you have opened.

Basic Layout

VS Code comes with a simple and intuitive layout that maximizes the space provided for the editor while leaving ample room to browse and access the full context of your folder or project. The UI is divided into five areas:

Editor - The main area to edit your files. You can open as many editors as you like side by side vertically and horizontally.

SideBar - Contains different views like the Explorer to assist you while working on your project.

Status Bar - Information about the opened project and the files you edit.

Activity Bar - Located on the far left-hand side, this lets you switch between views and gives you additional context-specific indicators, like the number of outgoing changes when Git is enabled.

Panels - You can display different panels below the editor region for output or debug information, errors, and warnings, or an integrated terminal. Panel can also be moved to the right for more vertical space.

Each time you start VS Code, it opens up in the same state it was in when you last closed it. The folder, layout, and opened files are preserved.

Open files in each editor are displayed with tabbed headers (Tabs) at the top of the editor region. To learn more about tabbed headers, see the Tabs section below.

Tip: You can move the Side Bar to the right-hand side (View > Move Side Bar Right) or toggle its visibility (Ctrl+B).

Activity Bar

The Activity Bar on the left lets you quickly switch between Views. You can also reorder Views by dragging and dropping them on the Activity Bar or remove a View entirely (right-click Hide from Activity Bar).

Command Palette

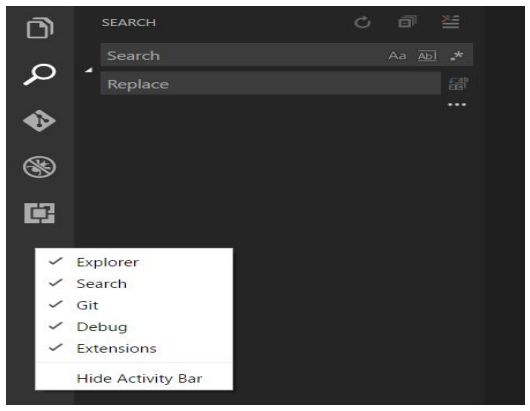
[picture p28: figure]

VS Code is equally accessible from the keyboard. The most important key combination to know is Ctrl+Shift+P, which brings up the Command Palette. From here, you have access to all of the functionality of the VS Code, including keyboard shortcuts for the most common operations.

The Command Palette provides access to many commands. You can execute editor commands, open files, search for symbols, and see a quick outline of a file, all using the same interactive window. Here are a few tips:

- Ctrl+P will let you navigate to any file or symbol by typing its name
- Ctrl+Shift+Tab will cycle you through the last set of files opened
- Ctrl+Shift+P will bring you directly to the editor commands
- Ctrl+Shift+O will let you navigate to a specific symbol in a file
- Ctrl+G will let you navigate to a specific line in a file

Type ? into the input field to get a list of available commands you can execute from here:

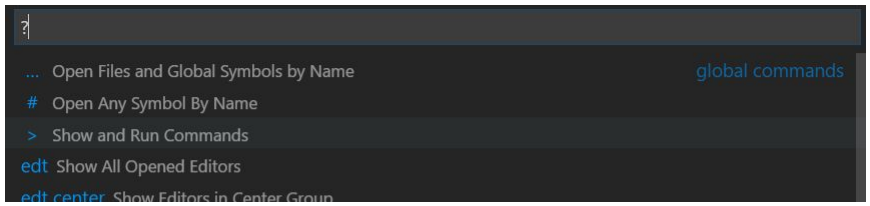
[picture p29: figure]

Disable Update VS Code Pop Up

When you start VS Code you may get pop up to update VS Code. As the eYFi-Mega Extension is tested on VS Code 1.36.0, we suggest you not to update your VS Code. To disable Update Pop up you can do the following,

1. Press Ctrl+comma to open settings.
2. Search for “Update: Mode” by typing update.mode in the search bar.
3. Set “Update: Mode” to manual.

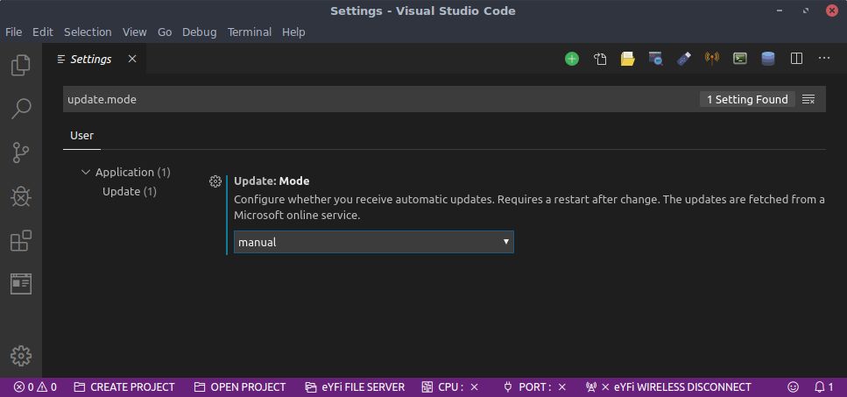
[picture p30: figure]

4. Now restart VS Code for this change to take effect.

## Installation of eYFi-Mega Extension and Toolchains in Linux

Installation of eYFi-Mega Extension

To install eYFi-Mega Extension two zip files need to be downloaded.,

- extensions.zip
- eY-Toolchain.zip

These two zip files can be downloaded from eYFi-Mega’s website which can be found at e-Yantra’s products page at https://e-yantra.org/products.

1. Extract the extension.zip file in the “data” folder of VS Code.

### 2. Extract the eY-Toolchain.zip in the “ey-ide-extn-vs-code” folder inside

the “extensions” folder.

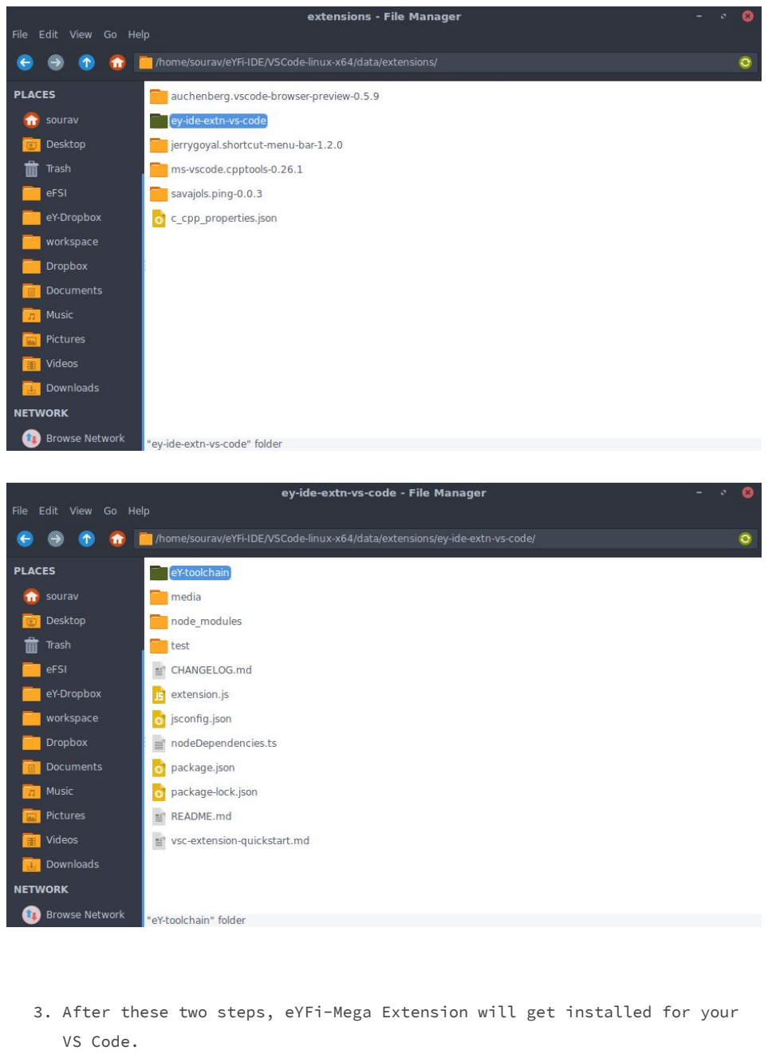
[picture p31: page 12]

### 3. After these two steps, eYFi-Mega Extension will get installed for your

VS Code.

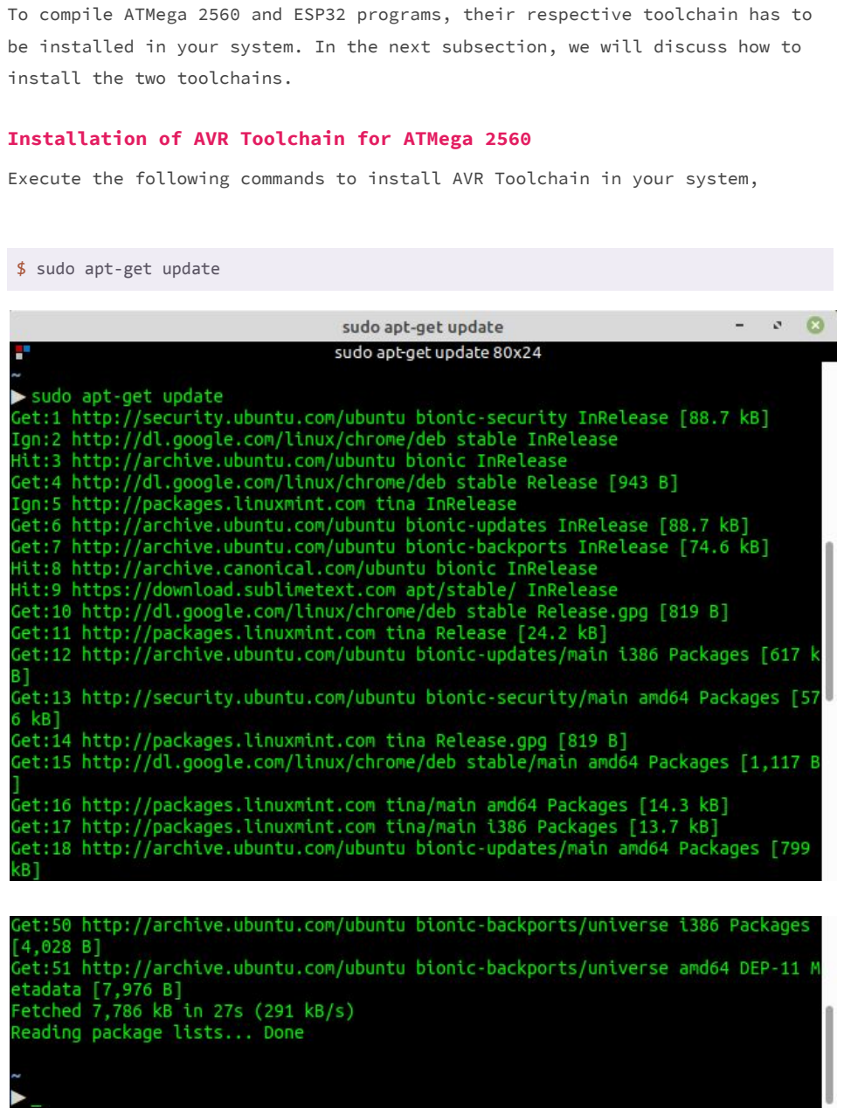
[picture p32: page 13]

To compile ATMega 2560 and ESP32 programs, their respective toolchain has to be installed in your system. In the next subsection, we will discuss how to install the two toolchains.

Installation of AVR Toolchain for ATMega 2560

Execute the following commands to install AVR Toolchain in your system,

$ sudo apt-get update

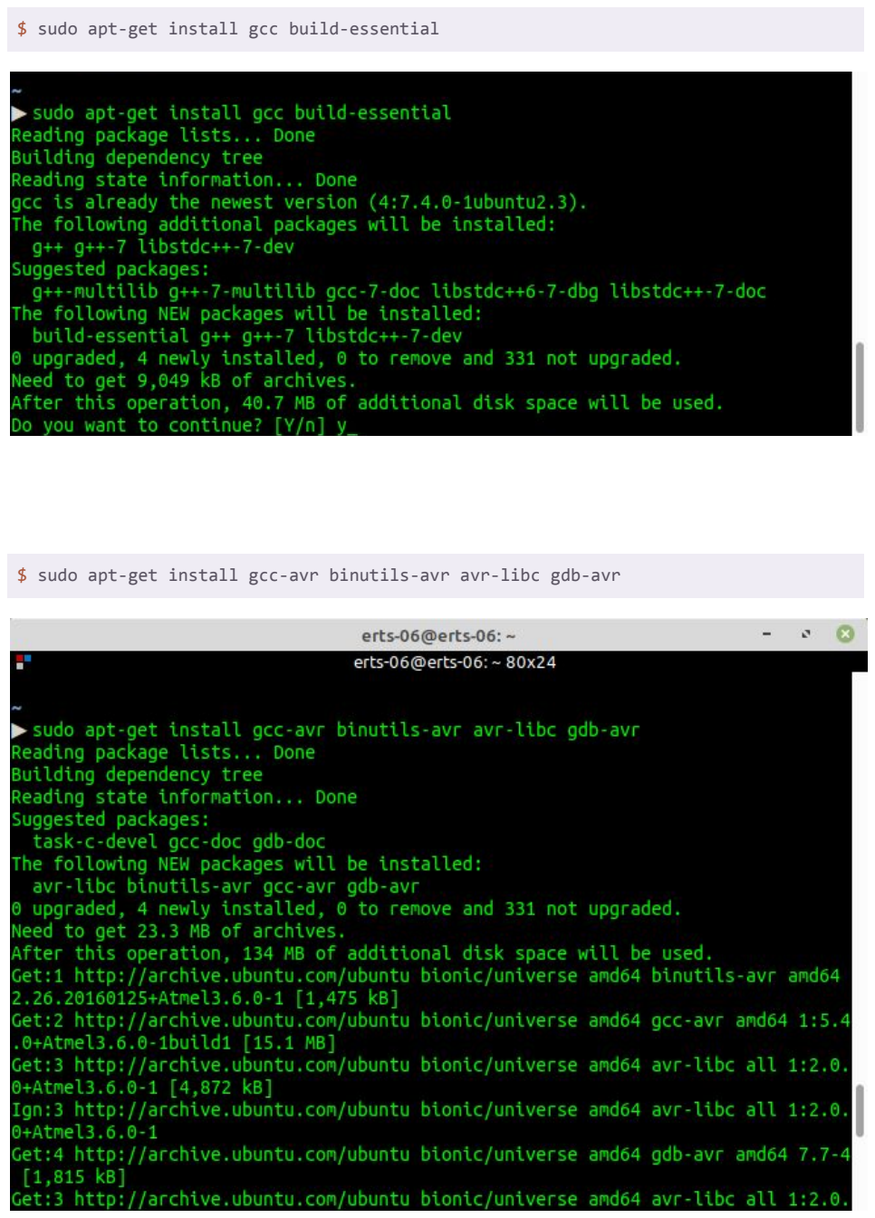
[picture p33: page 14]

$ sudo apt-get install gcc build-essential

$ sudo apt-get install gcc-avr binutils-avr avr-libc gdb-avr

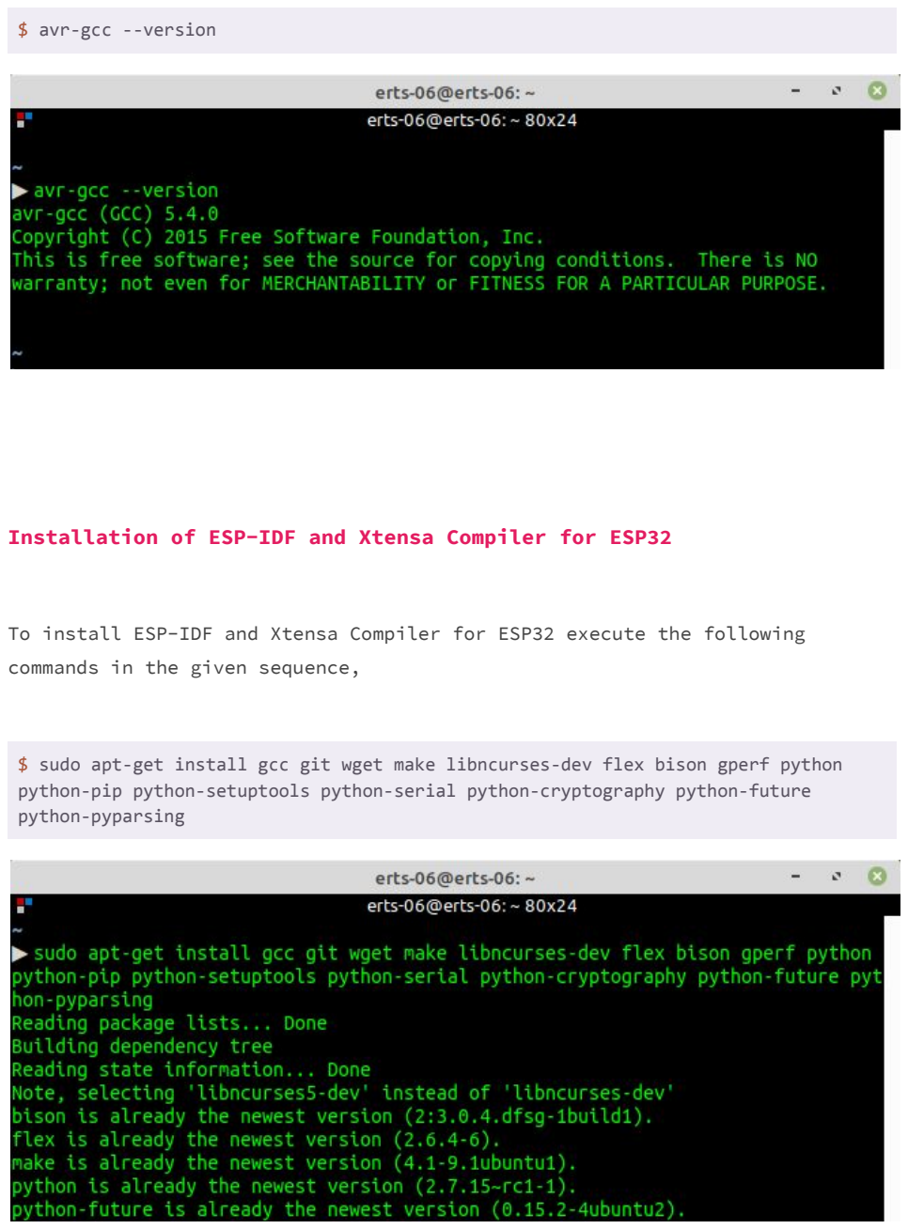
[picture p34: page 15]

$ avr-gcc --version

Installation of ESP-IDF and Xtensa Compiler for ESP32

To install ESP-IDF and Xtensa Compiler for ESP32 execute the following commands in the given sequence,

$ sudo apt-get install gcc git wget make libncurses-dev flex bison gperf python python-pip python-setuptools python-serial python-cryptography python-future python-pyparsing

$ mkdir -p ~/esp

$ cd ~/esp

Download Xtensa Compiler

for 64-bit Linux:
https://dl.espressif.com/dl/xtensa-esp32-elf-linux64-1.22.0-80-g6c4433a-5.2.0.tar.gz (https://dl.espressif.com/dl/xtensa-esp32-elf-linux64-1.22.0-80-g6c4433a-5.2.0.tar.gz)

for 32-bit Linux:
https://dl.espressif.com/dl/xtensa-esp32-elf-linux32-1.22.0-80-g6c4433a-5.2.0.tar.gz (https://dl.espressif.com/dl/xtensa-esp32-elf-linux32-1.22.0-80-g6c4433a-5.2.0.tar.gz)

$ tar -xzf ~/Downloads/xtensa-esp32-elf-linux64-1.22.0-80-g6c4433a-5.2.0.tar.gz

$ git clone -b v3.3 --recursive https://github.com/espressif/esp-idf.git

Now the esp folder should have following two folders

### 1. esp-idf 2. xtensa-esp32-elf

Use the following command to check folders in the esp folder

$ ls -l

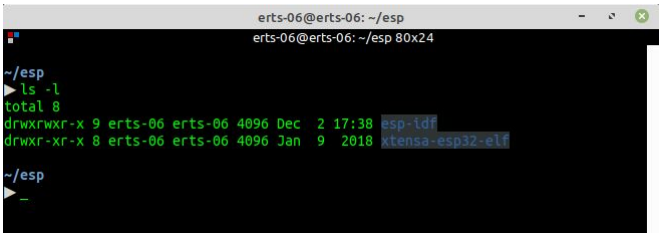
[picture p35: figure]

$ export PATH="$HOME/esp/xtensa-esp32-elf/bin:$PATH"

$ export IDF_PATH=~/esp/esp-idf

$ sudo python -m pip install --user -r $IDF_PATH/requirements.txt

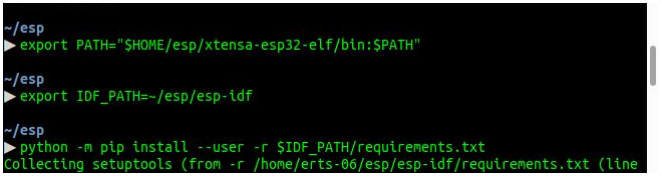
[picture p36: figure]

Do the following to set the environment variables for ESP32

If you are using BASH shell, execute the following command

$ sudo gedit ~/.bashrc

If you are using ZSH shell, execute the following command

$ sudo gedit ~/.zshrc

NOTE: Most of the major Linux Distributions like Ubuntu uses BASH Shell.

Once the text editor opens up add the following lines at the end of the file,

#ESP32

export IDF_PATH=~/esp/esp-idf
export PATH="$HOME/esp/xtensa-esp32-elf/bin:$PATH"

Save and close the text editor.

To check the Environment Variables execute the following commands,

$ printenv IDF_PATH

$ printenv PATH

Dial Out

The currently logged user should have read and write access to the serial port over USB. On most Linux distributions, this is done by adding the user to dialout group with the following command:

$ sudo usermod -a -G dialout $USER

If the above command does not work, use the following command

$ sudo chmod 777 /dev/ttyUSB0

## Using eYFi-Mega Extension

Buttons of eYFi-Mega Extension

On the top right corner, you can find several buttons that are useful for development on the eYFi-Mega Board.

Button - Create Project

Using this button you can create projects for ESP32 and ATMega2560.

When you press this button a window to select target microcontroller will pop-up. Using this window you can select one of the microcontroller for which you want to create project.

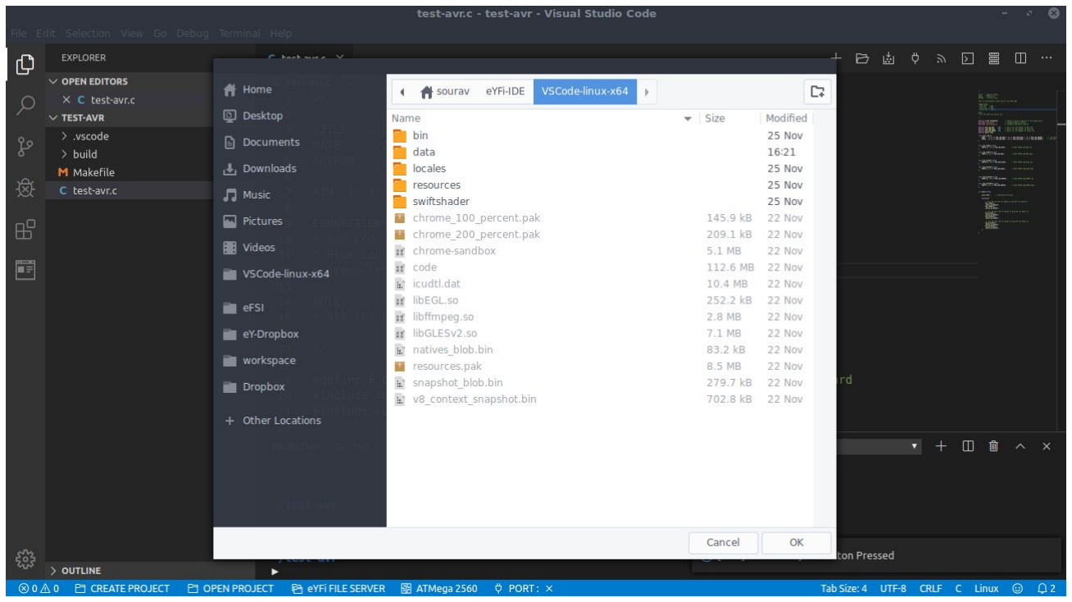
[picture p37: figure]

After selecting the target microcontroller, a file explorer will pop up. Using this file explorer first navigate to the folder where you want to save your project and then create a folder with your project name. Then open your project folder and click OK.

NOTE: Make sure your project name does not contain any whitespace.

After that, the extension will populate your project folder with the necessary files.

NOTE: For ESP32 projects, you can find the source file in the main folder

Button - Open Project

You can use this button to open your existing eYFi-Mega projects. When you click this button a file explorer will pop-up. Using this you can navigate to your project folder and then open it.

NOTE: We recommend not to use this button to open your non eYFi-Mega projects. Use VS Code’s native menubar for that.

Button - Compile

Use this button to compile and generate the binary and hex file of your application.

If the build is successful for ATMega 2560, all the object files, the hex file, and the binary file of your application will get generated inside the build folder in the project directory.

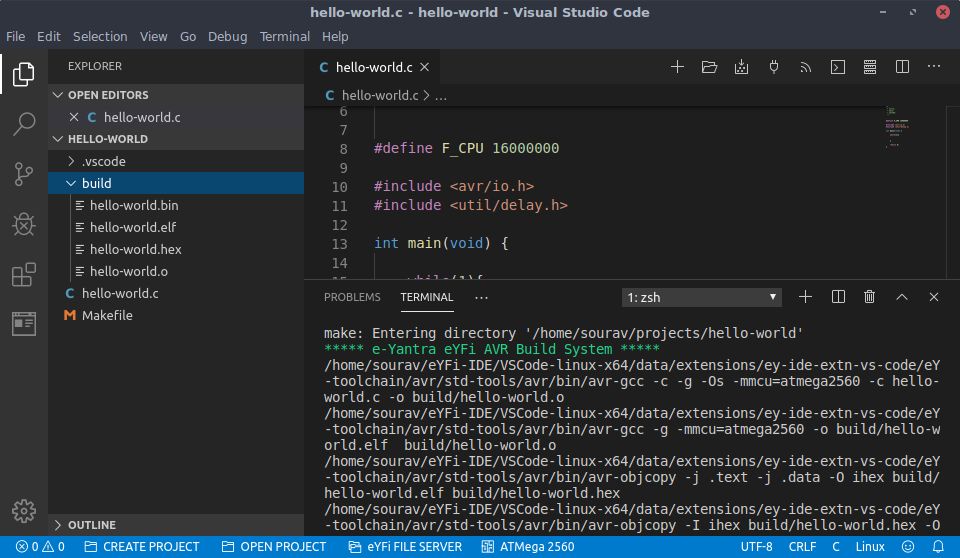
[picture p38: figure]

When the build is successful for ESP32, bin file will get generated in the build folder and you will get the following message in the terminal,

“To flash all build output, run 'make flash' or:”

All the errors and warnings, if there is any, will get displayed in the same terminal.

Button - Wired Flash

Use this button to flash the binary file in the microcontroller using the serial port.

When you press this button and if the serial port to which your eYFi-Mega is connected is not set, a window to select serial port will pop up. Once you select the serial port, the flashing process will start.

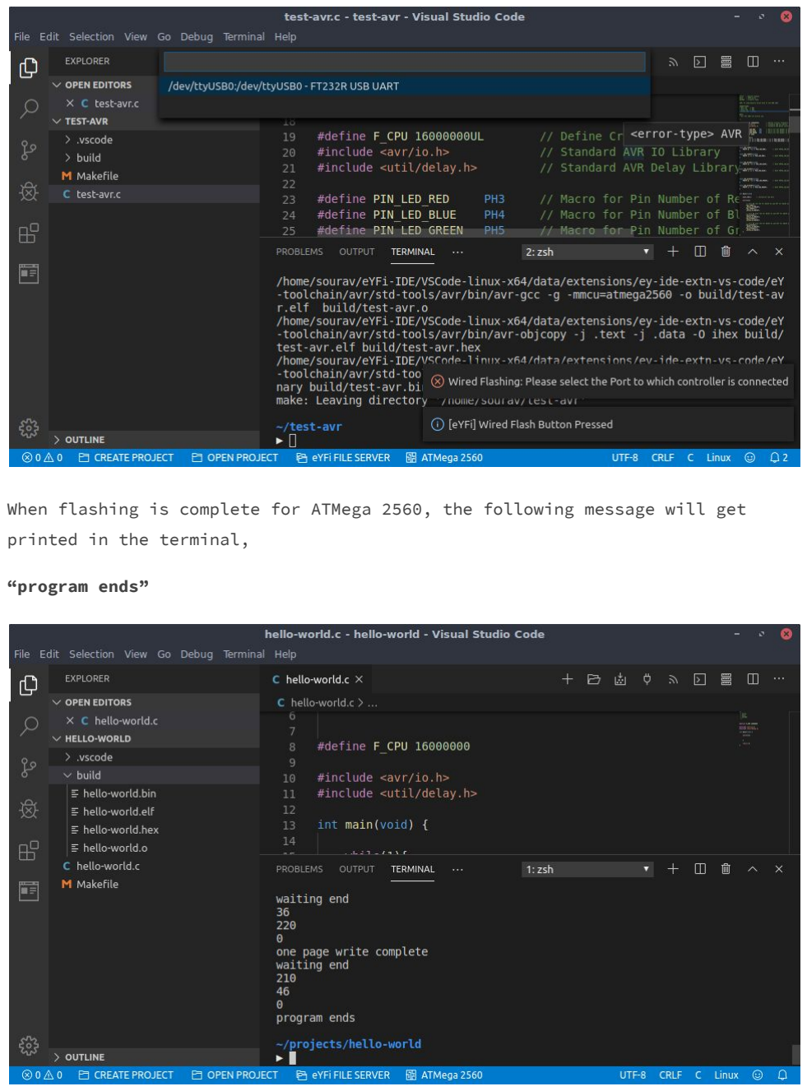
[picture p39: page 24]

When flashing is complete for ATMega 2560, the following message will get printed in the terminal,

“program ends”

When flashing is complete for ESP32, the following message will get printed in the terminal,

“Hard resetting via RTS pin…”

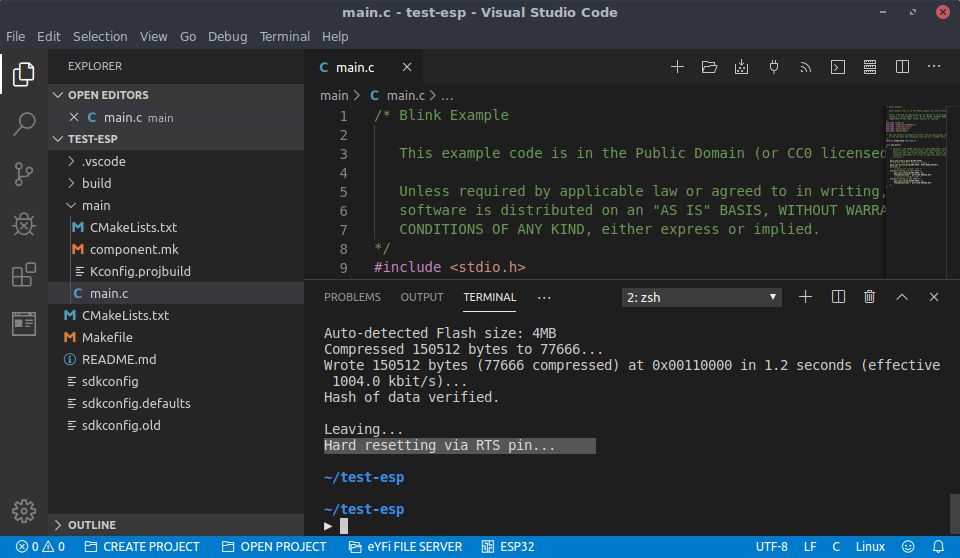
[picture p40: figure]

NOTE: When flashing make sure that switch S1 is in the correct position.

Button - Wireless Flash

Use this button to flash the binary file in the microcontroller over Wi-Fi.

Before you start Wireless Flashing make sure that you are connected to the Wireless Access Point of eYFi-Mega.

Once you are connected to the Wireless Access Point, the following message will get displayed in the status bar below.

If you are not connected to the Wireless Access Point, the following message will get displayed instead,

Once you are connected to eYFi-Mega’s Wireless Access Point you can do Wireless Flashing.

After you press the button first compilation will start and after compilation uploading of the generated bin file will start. When this starts, “Uploading File” will get printed in the terminal.

During this time keep an eye on the Wi-Fi Status LED on the board. When the file is getting uploaded to the file server Wi-Fi Status LED will turn OFF. Once the upload is done, the flashing process will start and the Wi-Fi Status LED will start blinking fast. After flashing is done Wi-Fi Status LED will start blinking slowly and “Uploading File Done” will get printed in the terminal.

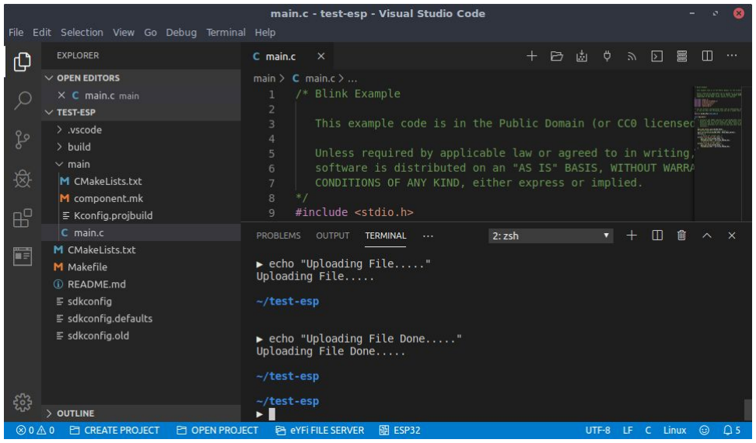
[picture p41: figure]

NOTE: For ESP32 you need to switch to user application manually using the S3 switch present on the board once Wireless Flashing is done.

Button - eYFi File Server

eYFi-Mega File Server is like a file explorer for the 700 KB on-board storage. You can use this storage to store any files like you can use this storage to configure the WiFi-SSID and Password of eYFi-Mega’s Wireless Access Point (explained in the next section), log data from sensors, you can even store .bin or .hex files of your firmware and flash it in any of the two controllers through this file server.

NOTE: When you are setting the name of your file which is to be uploaded, keep the name of the file including the name of the extension less than 31 characters in length.

Before you press this button make sure that you are connected to eYFi-Mega’s Wireless Access Point.

When you press this button, application to access file server hosted by eYFi-Mega will start.

Button - Wired Serial Monitor

This button will open up an instance of CoolTerm.

To start Serial Terminal first press the Options button of CoolTerm and select the appropriate port and baud rate.

For ATMega 2560, turn ON DTR and RTS.

For ESP32, turn OFF DTR and RTS.

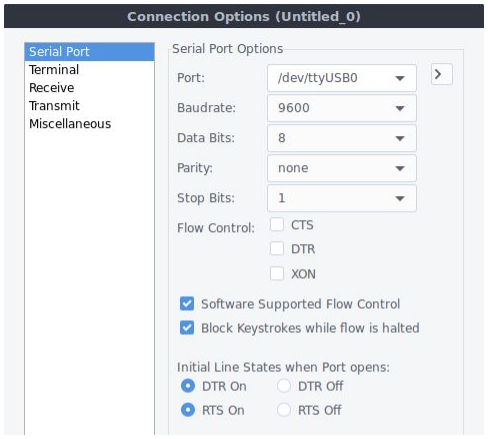
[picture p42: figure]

Status Bar

The status bar contains some useful buttons and indicators for the eYFi-Mega board.

Indicators

### 1. Selected Microcontroller - This will indicate the microcontroller used

in the project.

### 2. eYFi Wireless Connection Status - This will indicate whether your

computer is connected to eYFi-Mega’s Wireless Access Point or not.

Buttons

### 1. Create Project - This button can also be used to create project for

eYFi-Mega.

### 2. Open Project - This button can also be used to Open any existing

eYFi-Mega Project.

### 3. eYFi File Server - This button can also be used to access eYFi File

Server.

Keyboard Shortcuts

VS Code allows you to set your own keyboard shortcuts for various buttons. To set your own shortcuts for the buttons of eYFi-Mega extension follow the following steps,

### 1. First, open keyboard shortcuts settings by going to File -> Preferences

-> Keyboard Shortcuts

### 2. Then in the search bar, search the following things to select eYFi-Mega

Extensions buttons
a. Create Project Button - extension.create
b. Open Project Button - extension.open
c. Build Button - extension.compile
d. Wired Flash Button - extension.wiredFlash
e. Wireless Flash Button - extension.wirelessFlash
f. Wired Serial Monitor Button - extension.wiredSerial
g. eYFi File Server Button - extension.fileServer

### 3. After selecting one button double click in the When cell and press the

key combination which you want to set as the shortcut for the button.

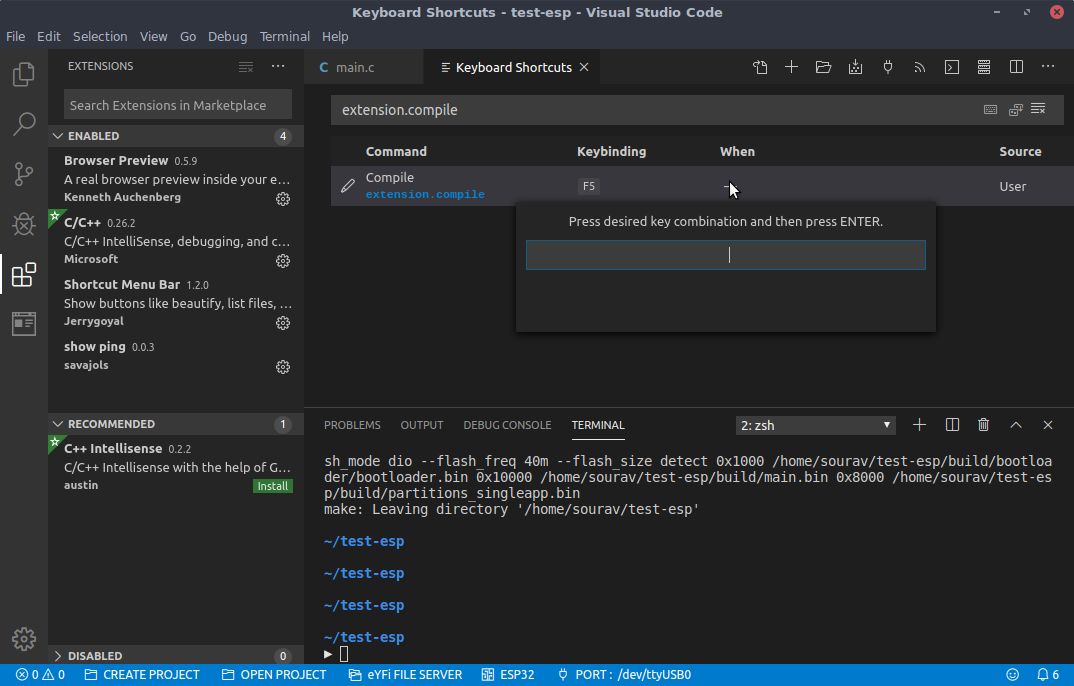
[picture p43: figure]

## Build System

ATMega 2560 Build System

We have developed our own Build System for ATMega 2560 projects. At the core of this build system we have a GNU Make Makefile which ties all the necessary AVR tools together.

This Makefile also allows you to add any third-party library to your project by simply copying the library files in the project folder.

There are few commands for this Makefile which you can use,

### 1. make all: This command will compile your source code and generate binary

and hex files.

### 2. make clean: This command will clean your project directory by removing

all the object files, binary file and hex file.

ESP32 Build System

For ESP32 we are using the default Build System developed by Espressif which comes with its own Makefile.

There are several handy commands for this Makefile which you can use,

### 1. make all: This command will compile your source code and generate binary

and executable files.

### 2. make -j5 all: The “j5” flag allows you to use all the 5 CPU cores for

the build process. This way build process can complete quickly if you use more than one core for the build process. Note: If you have 3 CPU cores use “j3” flag instead.

### 3. make clean: This command will clean your project directory by removing

all the object files.

### 4. make erase_flash: This will erase the entire 4 MB flash of ESP32. NOTE:

Using this command will erase OTA Application, Partition Table and File Storage of eYFi-Mega.

### 5. make flash: This command will flash your application in the factory

partition of ESP32. WARNING: eYFi-Mega OTA Application resides in factory partition. If you execute this command OTA Application will get replaced with your application.
6. make monitor: This will open a serial monitor for ESP32 in the terminal.
7. make menuconfig: This command will open a menu-driven user interface, which will allow you to choose the features of ESP32 that you want to have in your application.

Using Makefile Commands

To use Makefile commands navigate to the eYFi-Mega project directory and open the terminal there. Make sure that the Makefile is present in the project directory.

Now in the terminal type the commands which you want to execute.

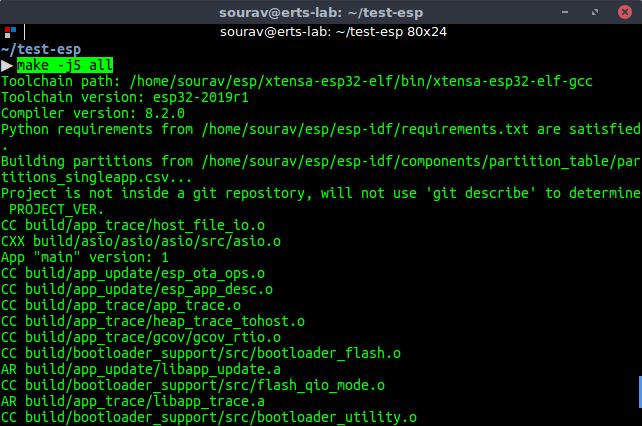
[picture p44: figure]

Adding Third-Party Libraries

To add any third-party library to your ATMega 2560 project, simply copy and paste the library source files in the project directory where your main C file exists. For ESP32, copy and paste the library source files in the main folder where your main C file exists. The Makefiles will take care of compiling and linking your library with your main source file.

## eYFi-Mega OTA Application

The eYFi-Mega OTA Application which resides in the factory partition of ESP32, allows user to flash the firmware of ATMega 2560 or ESP32 wirelessly and gives access to the file storage of eYFi-Mega.

eYFi-Mega File Server

eYFi-Mega File Server is like a file explorer for the 700 KB onboard storage. To access this file server you need to first connect to eYFi-Mega’s Wireless Access Point. After connecting to the Access Point you can use VS Code with eYFi-Mega Extension to open the file server window. You can use this storage to store any files like you can use this storage to configure your WiFi-SSID and password (explained in the next section), log data from sensors, you can even store .bin or .hex files of your firmware and flash it in any of the two controllers through this file server.

NOTE: When you are setting the name of your file which is to be uploaded, keep the name of the file including the name of the extension less than 31 characters in length.

Set Wi-Fi SSID and Password

To set your own Wi-Fi SSID and Password of the board, upload a config.txt file to your eYFi-Mega File Server with your SSID and Password in the following format in the file. After the upload is done, reset the ESP32 by pressing the ESP_RESET button, and you are all set!

Filename: config.txt

WiFi-SSID [your-wifi-ssid]

WiFi-Pass [your-wifi-pass]

For example,

WiFi-SSID [eYFi-Mega]

WiFi-Pass [eyantra123]

will set the SSID to "eYFi-Mega" and Password to "eyantra123".

Default SSID and Password of eYFi-Mega Wireless Access Point

Wi-Fi SSID: | eYFi-Mega
Wi-Fi Password: | eyantra123

In case the config.txt file is missing from your file server or the format of the config.txt file is not proper then, this default SSID and Password will be set for your Wireless Access Point.

Wi-Fi Status LED Indication

When you are connected to your eYFi-Mega over a Wi-Fi link, it's important to know the different states in which your board is. These states are indicated by the Blue Wi-Fi Status LED, which is right next to Red ESP_ON LED. Below is the description of different LED Patterns associated with different states of the board.

State | LED Pattern
Wi-Fi Client is connected to ESP32 | ON
Wi-Fi Client is disconnected from ESP32 | OFF
File Upload Start | OFF
File Upload End | Blink Fast for 100 ms
Firmware Flash Start | Blink Fast
Firmware Flash End for AVR | Blink Slow for 5 s
Firmware Flash End for ESP32 | Blink Slow till application Switch #1 (S1) is toggled

## eYFi-Mega Wireless Serial Terminal Application

We have developed an ESP32 application which allows ATMega 2560 to transmit its data on UART #0 over Wi-Fi. So with the help of this application, you can receive serial data over Wi-Fi at your side.

To use this first, you would have to flash this application which you can download from eYFi-Mega’s website in the user-app partition of ESP32.

After that make sure the S2 switch is towards the Wi-Fi symbol. This will connect UART#0 of ATMega 2560 with UART#1 of ESP32.

To start this application switch S1 away from the Wi-Fi symbol and then press ESP_RESET button, to start the application.

In your ATMega 2560 application make sure that you are sending data to UART #0 at a baud rate of 115200.

To receive data on your Linux system you can use netcat utility. Run the following command in the terminal to receive data from the UART #0 of ATMega 2560 over Wi-Fi,

nc 192.168.4.1 3333

You can also run this command on your Android Device. To run terminal commands on your Android Device use Termux App which you can download from Google Play Store. Termux App Download URL (https://play.google.com/store/apps/details?id=com.termux&hl=en_IN)

Before you run this command, make sure that you are connected to the Wireless Access Point of eYFi-Mega. For this application the Wi-Fi SSID is eYFi-Wireless-Serial and there is no password.

In the Quick Bytes page of eYFi-Mega which you can find at eYFi-Mega’s website, you can find the example code for using this Wireless Serial Terminal.

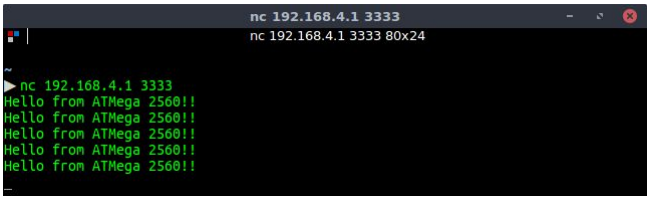
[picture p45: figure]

## eYFi-Mega ESP32 Partition Table

We have partitioned the 4 MB flash of onboard ESP32 to accommodate 1 MB OTA App, 2 MB for User App and 700 KB for File Storage. This partition table can be modified by you as per your requirement. For example, if you want to increase or decrease the size of the 700 KB File Storage you can update the partition table. If you decide to modify the partition table for your project, you might not be able to use the OTA App because our OTA App is compatible with the partition table described below. In case you accidentally erase the partition you can always download our Partition Table and our OTA App from our website. The current partition table is described below,

Partition Name | Start Address | Size
reserved area (nvs, otadata, phy_init) | - 300 KB
factory (ota-app) | 0x10000 | 1 MB
app1 (user-app) | 0x110000 | 2 MB
storage (spiffs) | 0x310000 | 700 KB

## Flashing ESP32 Bootloader, Partition Table, OTA Application, Wireless Serial Terminal Application and ESP32 User Application in eYFi-Mega

In case you accidentally erase any of the important firmware which is required for eYFi-Mega to function properly, you can always download them from our website and flash them again. In this section, we will discuss how you can do that.

To flash firmware in ESP32 you would need esptool.

The esptool and the firmware described in the following sections can be downloaded from eYFi-Mega’s website which can be found at e-Yantra’s products page at https://e-yantra.org/products.

Flashing eYFi-Mega ESP32 Bootloader

Copy the bootloader file in the esptool folder and execute the following command to flash the bootloader

$ python2 esptool.py -b 921600 --port /dev/ttyUSB0 write_flash 0x1000 eyfi-mega_esp32_bootloader.bin

Flashing eYFi-Mega ESP32 Partition Table

Copy the partition table file in the esptool folder and execute the following command to flash the partition table.

$ python2 esptool.py -b 921600 --port /dev/ttyUSB0 write_flash 0x8000 eyfi-mega_esp32_partitions.bin

Flashing eYFi-Mega ESP32 OTA Application

Copy the OTA Application file in the esptool folder and execute the following command to flash the OTA Application

$ python2 esptool.py -b 921600 --port /dev/ttyUSB0 write_flash 0x10000 eyfi-mega_esp32_ota_app.bin

Flashing eYFi-Mega ESP32 User Application and Wireless Serial Terminal Application

Copy the Wireless Serial Terminal Application or User Application file in the esptool folder and execute the following command to flash the file

$ python2 esptool.py -b 921600 --port /dev/ttyUSB0 write_flash 0x110000 eyfi-mega_esp32_user_app.bin

## APPENDIX

APPENDIX A: Kill Any Command

While any command is being executed either in your terminal or in VS Code’s terminal and you want to kill it, just press CTRL+C in the terminal.

APPENDIX B: Unix and Blank Spaces

Unix systems are not good in handling blank spaces so, we recommend not to have any blank spaces in your folder name or filename. Use camelCase or snake_case instead of having a blank space between two words.

APPENDIX C: Set Python 2 as your default Python Interpreter

It might be possible that Python 3 is your default Python interpreter in your environment. If that is the case some of the python commands used by the ESP32 build system and eYFi-Mega VS Code Extension might not work because they use Python 2.

To check your default python interpreter version enter the following command in your terminal,

$ python --version

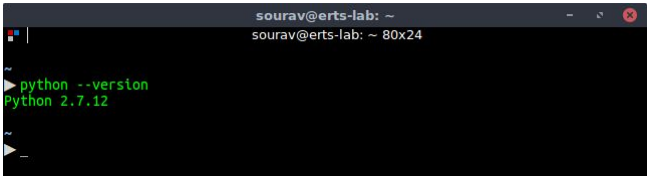
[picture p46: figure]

If your Python version is 2.x then you are good to go. But, if it is 3.x then you would have to set Python 2 as your default interpreter for your environment. To do so, follow the following steps,

If you are using BASH shell, execute the following command

$ sudo gedit ~/.bashrc

If you are using ZSH shell, execute the following command

$ sudo gedit ~/.zshrc

This command will open up the shell settings file in gedit text editor.

NOTE: Most of the major Linux Distributions like Ubuntu uses BASH Shell.

Go to the end of the file and add the following line,

alias python='python2'

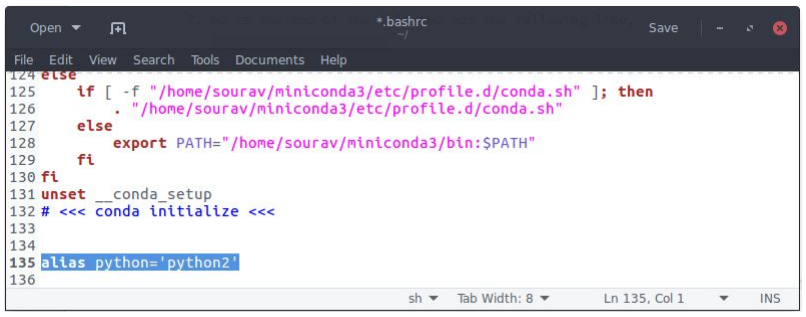
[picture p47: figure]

Make sure to save and then exit the text editor.

Close the terminal and open it again and enter the following command,

$ python --version

Now Python 2 will be set as you default python interpreter.
*******

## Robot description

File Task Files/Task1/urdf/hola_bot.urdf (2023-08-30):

<?xml version="1.0" encoding="utf-8"?>
<!--First version of this URDF was automatically created by SolidWorks to URDF Exporter!
    as part of eYSIP 2022 
    Originally created by Stephen Brawner (brawner@gmail.com) 
    Commit Version: 1.6.0-4-g7f85cfe  Build Version: 1.6.7995.38578
    For more information, please see http://wiki.ros.org/sw_urdf_exporter 

    This version of the URDF is made after a lot of simplification by the e-Yantra Team (Arjun Sadananda) -->

<robot name="hola_bot">

  <!-- Chassis -->

  <link name="base_link">
    <inertial>
      <origin xyz="0 0 0" rpy="0 0 0" />
      <mass value="0.49" />
      <inertia ixx="0.00199" ixy="0" ixz="0" iyy="0.00199" iyz="0" izz="0.00395" />
    </inertial>
    <visual>
      <origin xyz="0 0 0" rpy="0 0 1.57" />
      <geometry>
        <mesh filename="package://hola_bot_basics/meshes/base_link.STL" />
      </geometry>
    </visual>
    <collision>
      <origin xyz="0 0 -0.01" rpy="0 0 1.57" />
      <geometry>
        <cylinder radius="0.15" length="0.005"/>
      </geometry>
    </collision>
  </link>
  <!-- Front Wheel -->

  <!-- Front Wheel Link -->
  <link name="front_wheel">
    <inertial>
      <origin xyz="0 0 0" rpy="0 0 0" />
      <mass value="0.062" />
      <inertia ixx="0.000285" ixy="0" ixz="0" iyy="0.0005198" iyz="0" izz="0.0002851" />
    </inertial>
    <visual>
      <origin xyz="0 0 0" rpy="0 0 0" />
      <geometry>
        <mesh filename="package://hola_bot_basics/meshes/wheel.STL" />
      </geometry>
    </visual>
    <collision>
      <origin xyz="0 -.01 0" rpy="1.57 0 0" />
      <geometry>
        <cylinder radius=".03" length="0.02"/>
      </geometry>
    </collision>
  </link>
  <!-- Right Wheel -->

  <!-- Right Wheel Link -->
  <link name="right_wheel">
    <inertial>
      <origin xyz="0 0 0" rpy="0 0 0" />
      <mass value="0.062" />
      <inertia ixx="0.000285" ixy="0" ixz="0" iyy="0.0005198" iyz="0" izz="0.0002851" />
    </inertial>
    <visual>
      <origin xyz="0 0 0" rpy="0 0 0" />
      <geometry>
        <mesh filename="package://hola_bot_basics/meshes/wheel.STL" />
      </geometry>
    </visual>
    <collision>
      <origin xyz="0 -.01 0" rpy="1.57 0 0" />
      <geometry>
        <cylinder radius=".03" length="0.02"/>
      </geometry>
    </collision>
  </link> 

   <!-- Left Wheel -->

  <!-- Left Wheel Link -->
  <link name="left_wheel">
    <inertial>
      <origin xyz="0 0 0" rpy="0 0 0" />
      <mass value="0.062" />
      <inertia ixx="0.000285" ixy="0" ixz="0" iyy="0.0005198" iyz="0" izz="0.0002851" />
    </inertial>
    <visual>
      <origin xyz="0 0 0" rpy="0 0 0" />
      <geometry>
        <mesh filename="package://hola_bot_basics/meshes/wheel.STL" />
      </geometry>
    </visual>
    <collision>
      <origin xyz="0 -.01 0" rpy="1.57 0 0" />
      <geometry>
        <cylinder radius=".03" length="0.02"/>
      </geometry>
    </collision>
  </link> 

<joint name="front_joint" type="continuous">
    <origin xyz="0 0.17483 -0.0335" rpy="0 0 0" />
    <parent link="base_link" />
    <child link="front_wheel" />
    <axis xyz="0 -1 0" />
    <limit effort="5" velocity="5" />
  </joint>

<joint name="right_joint" type="continuous">
    <origin xyz="-0.15154 -0.087275 -0.0335" rpy="0 0 2.0943" />
    <parent link="base_link" />
    <child link="right_wheel" />
    <axis xyz="0 -1 0" />
    <limit effort="5" velocity="5" />
  </joint>

  <joint name="left_joint" type="continuous">
    <origin xyz="0.15154 -0.087275 -0.0335" rpy="0 0 -2.0943" />
    <parent link="base_link" />
    <child link="left_wheel" />
    <axis xyz="0 -1 0" />
    <limit effort="5" velocity="5" />
  </joint>
<gazebo>
    <plugin name="object_controller" filename="libgazebo_ros_planar_move.so">
      <commandTopic>cmd_vel</commandTopic>
      <odometryTopic>odom</odometryTopic>
      <odometryFrame>odom</odometryFrame>
      <odometryRate>20.0</odometryRate>
      <robotBaseFrame>base_link</robotBaseFrame>
    </plugin>
  </gazebo>
.
.
<!-- lot more stuff needs to go here -->
.
.
</robot>

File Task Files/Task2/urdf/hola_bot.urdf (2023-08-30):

<?xml version="1.0" encoding="utf-8"?>
<!--First version of this URDF was automatically created by SolidWorks to URDF Exporter!
    as part of eYSIP 2022 
    Originally created by Stephen Brawner (brawner@gmail.com) 
    Commit Version: 1.6.0-4-g7f85cfe  Build Version: 1.6.7995.38578
    For more information, please see http://wiki.ros.org/sw_urdf_exporter 

    This version of the URDF is made after a lot of simplification by the e-Yantra Team (Arjun Sadananda) -->
<robot name="hola_bot">

  <!-- Chassis -->

  <link name="base_link">
    <inertial>
      <origin xyz="0 0 0" rpy="0 0 0" />
      <mass value="1" />
      <inertia ixx="0.005627" ixy="0" ixz="0" iyy="0.005627" iyz="0" izz="0.01125" />
    </inertial>
    <visual>
      <origin xyz="0 0 0" rpy="0 0 1.57" />
      <geometry>
        <mesh filename="package://your_package_name/meshes/base_link.obj" />
      </geometry>
    </visual>
    <collision>
      <origin xyz="0 0 -0.01" rpy="0 0 1.57" />
      <geometry>
        <cylinder radius="0.15" length="0.005"/>
      </geometry>
    </collision>
  </link>


  <!-- Front Wheel -->

  <!-- Front Wheel Link -->
  <link name="front_wheel">
    <inertial>
      <origin xyz="0 0 0" rpy="0 0 0" />
      <mass value="0.060" />
      <inertia ixx="0.00001352" ixy="0" ixz="0" iyy="0.000027" iyz="0" izz="0.00001352" />
    </inertial>
    <visual>
      <origin xyz="0 0 0" rpy="0 0 0" />
      <geometry>
        <mesh filename="package://your_package_name/meshes/wheel.STL" />
      </geometry>
    </visual>
    <collision>
      <origin xyz="0 -.01 0" rpy="1.57 0 0" />
      <geometry>
        <cylinder radius=".03" length="0.02"/>
      </geometry>
    </collision>
  </link>

  <!-- Front Wheel Joint -->

  <joint name="front_joint" type="revolute">
    <origin xyz="0 0.17483 0" rpy="0 0 0" />
    <parent link="base_link" />
    <child link="front_wheel" />
    <axis xyz="0 -1 0" />
    <limit effort="5" velocity="5" />
  </joint>
  
  <!-- Left Wheel -->

  <!-- Left Wheel Link -->
  <link name="left_wheel">
    <inertial>
      <origin xyz="0 0 0" rpy="0 0 0" />
      <mass value="0.060" />
      <inertia ixx="0.00001352" ixy="0" ixz="0" iyy="0.000027" iyz="0" izz="0.00001352" />
    </inertial>
    <visual>
      <origin xyz="0 0 0" rpy="0 0 0" />
      <geometry>
        <mesh filename="package://your_package_name/meshes/wheel.STL" />
      </geometry>
      <material name="">
        <color rgba="0.4 0.4 0.4 1" />
      </material>
    </visual>
    <collision>
      <origin xyz="0 -0.01 0" rpy="1.57 0 0" />
      <geometry>
        <cylinder radius=".03" length="0.02"/>
      </geometry>
    </collision>
  </link>

  <!-- Left Wheel Joint -->
  <joint name="left_joint" type="revolute">
    <origin xyz="-0.15154 -0.087275 0" rpy="0 0 2.094" />
    <parent link="base_link" />
    <child link="left_wheel" />
    <axis xyz="0 1 0" />
    <limit effort="5" velocity="5" />
  </joint>


  <!-- Right Wheel -->
  <!-- Right Wheel Link -->
  <link name="right_wheel">
    <inertial>
      <origin xyz="0 0 0" rpy="0 0 0" />
      <mass value="0.060" />
      <inertia ixx="0.00001352" ixy="0" ixz="0" iyy="0.000027" iyz="0" izz="0.00001352" />
    </inertial>
    <visual>
      <origin xyz="0 0 0" rpy="0 0 0" />
      <geometry>
        <mesh filename="package://your_package_name/meshes/wheel.STL" />
      </geometry>
      <material name="">
        <color rgba="0.4 0.4 0.4 1" />
      </material>
    </visual>
    <collision>
      <origin xyz="0 -0.01 0" rpy="1.57 0 0" />
      <geometry>
        <cylinder radius=".03" length="0.02"/>
      </geometry>
    </collision>
  </link>

  <!-- Right Wheel Joint -->

  <joint name="right_joint" type="revolute">
    <origin xyz="0.15154 -0.087275 0" rpy="0 0 -2.094" />
    <parent link="base_link" />
    <child link="right_wheel" />
    <axis xyz="0 1 0" />
    <limit effort="5" velocity="5" />
  </joint>


 <gazebo>
    <plugin name="object_controller" filename="libgazebo_ros_planar_move.so">
    </plugin>
  </gazebo>   

 <gazebo>
    <plugin name="right_force" filename="libcustom_force.so" >
      <bodyName>right_wheel</bodyName>
      <topicName>right_wheel_force</topicName>
    </plugin>
  </gazebo>

  <gazebo>
    <plugin name="left_force" filename="libcustom_force.so" >
      <bodyName>left_wheel</bodyName>
      <topicName>left_wheel_force</topicName>
    </plugin>
  </gazebo>

  <gazebo>
    <plugin name="front_force" filename="libcustom_force.so" >
      <bodyName>front_wheel</bodyName>
      <topicName>front_wheel_force</topicName>
    </plugin>
  </gazebo>
  
</robot>

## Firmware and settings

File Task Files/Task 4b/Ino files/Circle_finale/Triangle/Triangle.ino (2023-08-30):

#include <AccelStepper.h>

/*Global Variable*/
unsigned long start_Time;

float v1;
float v2;
float v3;
/*CODE*/
AccelStepper ystepper(1,oc4a,oc4b);
AccelStepper rtstepper(1,oc2a,oc1a);
AccelStepper ltstepper(1,oc5b,oc5c);

void setup()
{
  // put your setup code here, to run once:
  ystepper.setMaxSpeed(1000);
  rtstepper.setMaxSpeed(1000);
  ltstepper.setMaxSpeed(1000);
}

void inv_kin(float Vx,float Vy,float W)
{
	//BLA::Matrix<3,1> body_vel = {Vx,Vy,W};
	//BLA::Matrix<3,3> trans_mat = {0.66667,0,1.90661,-0.333333,0.57737,1.90661,-0.333333,-0.57737,1.90661};
	//BLA::Matrix<3,1> wheel_vel = trans_mat* body_vel;
	// BLA::speed_of_each_wheel(wheel_vel(1,1),wheel_vel(2,1),wheel_vel(3,1));
  v1 = 0.66667*Vx + 1.90661*W;
  v2 = -0.333333*Vx + 0.57737*Vy + 1.90661*W;
  v3 = -0.333333*Vx - 0.57737*Vy + 1.90661*W;

  Serial.println(v1);

  ystepper.setSpeed(v1*400);
  rtstepper.setSpeed(v2*400);
  ltstepper.setSpeed(v3*400);
  ystepper.runSpeed();
  rtstepper.runSpeed();
  ltstepper.runSpeed();


}
void UD(unsigned long t)
{
	unsigned long current_Time = millis();
	while (current_Time - t <= 6200 )
	{
		if (current_Time -t <= 3000)
		{
			inv_kin(0,1,0);

			current_Time = millis();	
		}
    if(3000< current_Time-t <3200){
      inv_kin(0, 0, 0);
      	current_Time = millis();
    }
		if (current_Time - t >= 3200)
		{
			inv_kin(0,-1,0);
			current_Time = millis();
		}
	}
}

void LR(unsigned long t)
{
	unsigned long current_Time = millis();
	while (current_Time - t <= 6500 )
	{
		if (current_Time -t <= 3000)
		{
			inv_kin(-1,0,0);
			current_Time = millis();	
		}
		if(3000< current_Time-t <3500){
      inv_kin(0, 0, 0);
      	current_Time = millis();
    }
		if (current_Time - t >= 3500)
		{
			inv_kin(1,0,0);
			current_Time = millis();
		}
	}	
}

void Tri(unsigned long t)
{
	unsigned long current_Time = millis();
	while (current_Time - t <= 15400 )
	{
		if (current_Time -t <= 5000)
		{
			inv_kin(0,1,0);
			current_Time = millis();	
		}
			if(5000< current_Time-t <5200){
      inv_kin(0, 0, 0);
      	current_Time = millis();
    } 
		if (current_Time - t <= 10200 && current_Time - t>=5200) 
		{
			inv_kin(0.866025,-0.5,0);
			current_Time = millis();
		}
  	if(10200< current_Time-t <10400){
      inv_kin(0, 0, 0);
      	current_Time = millis();
    }
		if (current_Time - t >= 10400)
		{
			inv_kin(-0.866025,-0.5,0);
			current_Time = millis();	
		}

	}
}

void circ(unsigned long t)
{
	 int a=1;
	float arg;
	unsigned long current_Time = millis();
	while (current_Time - t <= 10000)
	{
		arg = 3.1416*0.2*((current_Time - t)/1000.0);
		inv_kin(-a*sin(arg),a*cos(arg),0);
    //delay(100);
		current_Time = millis();
   // Serial.println(-a*sin(arg));
 // Serial.println(a*cos(arg));
  
  
	}
}

void move_bot()
{
	start_Time = millis();
	UD(start_Time);
  delay(500);
  	start_Time = millis();
	LR(start_Time);
   delay(500);
  // start_Time = millis();
  // Tri(start_Time);
  // start_Time=millis();
  // circ(start_Time);
 }





void loop() {
  // put your main code here, to run repeatedly:
 move_bot();
 
}

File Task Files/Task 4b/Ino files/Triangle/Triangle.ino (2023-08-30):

#include <AccelStepper.h>
//#include <BasicLinearAlgebra.h>

/*Global Variable*/
unsigned long start_Time;

float v1;
float v2;
float v3;
/*CODE*/
const int STEP_PIN1 = oc4a;
const int STEP_PIN2 = oc2a;
const int STEP_PIN3 = oc5b;

const int DIR_PIN1 = oc4b;
const int DIR_PIN2 = oc1a;
const int DIR_PIN3 = oc5c;

unsigned long time1 = millis();
unsigned long time2 = millis();
unsigned long time3 = millis();

void runSpeed(float v1,float v2, float v3)

{
  v1>0?digitalWrite(DIR_PIN1,HIGH):digitalWrite(DIR_PIN1,LOW);
  v2>0?digitalWrite(DIR_PIN2,HIGH):digitalWrite(DIR_PIN2,LOW);
  v3>0?digitalWrite(DIR_PIN3,HIGH):digitalWrite(DIR_PIN3,LOW);

  if (millis() - time1 >= (1000/v1)) {
    digitalWrite(STEP_PIN1, HIGH);
    delayMicroseconds(2);
    digitalWrite(STEP_PIN1, LOW);
    time1 = millis();
  }
  if (millis() - time2 >= (1000 / v2)) {
    digitalWrite(STEP_PIN2, HIGH);
    delayMicroseconds(2);
    digitalWrite(STEP_PIN2, LOW);
    time2 = millis();
  }
  if (millis() - time3 >= (1000 / v3)) {
    digitalWrite(STEP_PIN3, HIGH);
    delayMicroseconds(2);
    digitalWrite(STEP_PIN3, LOW);
    time3 =millis();
    }
}

void setup() {
  // put your setup code here, to run once:
  Serial.begin(9600);
  
  // move_bot();
}

void inv_kin(float Vx,float Vy,float W)
{
	//BLA::Matrix<3,1> body_vel = {Vx,Vy,W};
	//BLA::Matrix<3,3> trans_mat = {0.66667,0,1.90661,-0.333333,0.57737,1.90661,-0.333333,-0.57737,1.90661};
	//BLA::Matrix<3,1> wheel_vel = trans_mat* body_vel;
	// BLA::speed_of_each_wheel(wheel_vel(1,1),wheel_vel(2,1),wheel_vel(3,1));
  v1 = 0.66667*Vx + 1.90661*W;
  v2 = -0.333333*Vx + 0.57737*Vy + 1.90661*W;
  v3 = -0.333333*Vx - 0.57737*Vy + 1.90661*W;

  Serial.println(v1);
  Serial.println(v2);
  Serial.println(v3);
  runSpeed(v1*300, v2*300, v3*300);


}
void UD(unsigned long t)
{
	unsigned long current_Time = millis();
	while (current_Time - t <= 6000 )
	{
		if (current_Time -t <= 3000)
		{
			inv_kin(0,1,0);

			current_Time = millis();	
		}
		if (current_Time - t >= 3000)
		{
			inv_kin(0,-1,0);
			current_Time = millis();
		}
	}
}

void LR(unsigned long t)
{
	unsigned long current_Time = millis();
	while (current_Time - t <= 6000 )
	{
		if (current_Time -t <= 3000)
		{
			inv_kin(-1,0,0);
			current_Time = millis();	
		}
		
		if (current_Time - t >= 3000)
		{
			inv_kin(1,0,0);
			current_Time = millis();
		}
	}	
}

void Tri(unsigned long t)
{
	unsigned long current_Time = millis();
	while (current_Time - t <= 15000 )
	{
		if (current_Time -t <= 5000)
		{
			inv_kin(1,0,0);
			current_Time = millis();	
		}
		
		if (5000 <= current_Time - t <= 10000)
		{
			inv_kin(-0.5,0.866025,0);
			current_Time = millis();
		}

		if (current_Time - t >= 15000)
		{
			inv_kin(-0.5,-0.866025,0);
			current_Time = millis();	
		}

	}
	delay(1000);
	start_Time = millis();
}

// void circ(unsigned long t)
// {
// 	int a;
// 	float arg;
// 	unsigned long current_Time = millis();
// 	while (current_Time - t <= 4000)
// 	{
// 		arg = 3.1416*0.5*((current_Time - t)/1000);
// 		inv_kin(-a*sin(arg),a*cos(arg),0);
// 		current_Time = millis();
	
// 	}
// 	delay(1000);	
	
// }

void move_bot()
{
	start_Time = millis();
	UD(start_Time);
  	start_Time = millis();
	LR(start_Time);
  // start_Time = millis();
  // Tri(start_Time);
}





void loop() {
  // put your main code here, to run repeatedly:
 move_bot();
}
